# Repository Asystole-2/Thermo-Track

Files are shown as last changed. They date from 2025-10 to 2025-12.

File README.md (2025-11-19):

# 🌡️ ThermoTrack

<div align="center">

**Smart Environmental Monitoring System**

*A universally designed smart monitoring system that observes room occupancy, temperature, and humidity to provide intelligent HVAC recommendations*





</div>

---

## ✨ Features

| Feature | Description |
|---|---|
| 🔐 **Secure Authentication** | Hashed passwords with HTTPS encryption |
| 🧠 **Smart HVAC Recommendations** | AI-driven suggestions based on occupancy and environmental data |
| 📊 **Real-time Dashboard** | Live monitoring of temperature, humidity, and occupancy |
| ⚡ **Energy Efficiency** | Promotes energy savings through intelligent recommendations |
| 👨‍💼 **Admin Policies** | Customizable comfort settings and energy-saving rules |
| 📱 **Universal Design** | Accessible and responsive for all users |

---

## 🛠️ Technology Stack

### **Frontend & Styling**




### **Backend & Database**




### **Hardware & Sensors**




### **Communication & Security**




---

## 🚀 Quick Start

### **Web Application Setup**

```bash
# Clone the repository
git clone https://github.com/Asystole-2/Thermo-Track.git
cd ThermoTrack/src/web

# Create virtual environment
python -m venv venv

# Activate virtual environment (Windows)
venv\Scripts\activate

# Install dependencies
pip install flask flask-mysqldb python-dotenv flask-session

# Run the application
flask run

# Clone the repository
git clone https://github.com/Asystole-2/Thermo-Track.git
cd Thermo-Track

# Install Raspberry Pi GPIO
sudo apt install -y python3-rpi.gpio

# Create and activate virtual environment
python3 -m venv venv
source venv/bin/activate

# Install dependencies
pip install -U pip
pip install python-dotenv 'pubnub>=10.4.1'

# Set up environment variables
cp .env.example .env
nano .env  # Add your PUBNUB keys

# Set Python path
export PYTHONPATH="$PWD/src"
```
---

## DHT22 Setup
```bash

DHT22 Pin → Raspberry Pi Pin
─────────────────────────────
VCC (Pin 1)   → 3.3V Power (Pin 1)
Data (Pin 2)  → GPIO 4 (Pin 7)
Ground (Pin 4) → Ground (Pin 6)

# Update package list
sudo apt-get update

# Install Python headers and GPIO dependencies
sudo apt-get install python3-dev libgpiod-dev -y

# Install required Python libraries
pip3 install adafruit-circuitpython-dht Adafruit-Blinka pubnub
```
---

### **🤖 AI Condition Suggester**
```bash
The AI-powered condition suggester analyzes real-time
environmental data (temperature, humidity, occupancy)
combined with local weather forecasts to provide
intelligent HVAC recommendations.
It uses Googles Gemini AI to generate
context-aware suggestions for optimal
comfort and energy efficiency.

# Install AI and weather dependencies
pip install google-generativeai requests python-dotenv

# Or install all dependencies at once:
pip install google-generativeai requests python-dotenv

# API Configuration
# AI and Weather API Keys
GEMINI_API_KEY=your_gemini_api_key_here
OPENWEATHER_API_KEY=your_openweather_api_key_here

# Optional: Default location for weather data
DEFAULT_CITY=Dublin
DEFAULT_COUNTRY=IE

🔑 Obtaining API Keys

-Google Gemini API
Visit Google AI Studio

Sign in with your Google account

Click "Create API Key" in the sidebar

Copy the generated key and add it to your .env file as GEMINI_API_KEY

-OpenWeather API
Register at OpenWeatherMap

Verify your email address

Navigate to the "API Keys" tab in your dashboard

Generate a new key (free tier includes 1,000 calls/day)

Copy the key and add it to your .env file as OPENWEATHER_API_KEY

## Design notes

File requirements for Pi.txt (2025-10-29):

sudo apt update
#install git
sudo apt install -y git
#clone repository
cd ~
git clone https://github.com/Asystole-2/Thermo-Track.git
cd Thermo-Track
# make sure you are in the right branch
#install Raspberry Pi GPIO
sudo apt install -y python3-rpi.gpio python3-dev gcc
#create and activate your virtual environment
python3 -m venv venv
source venv/bin/activate
#Install dependencies
pip install -U pip
pip install python-dotenv
pip install 'pubnub>=10.4.1'
#create .env check the .env.example file copy paste that one change only the PUBNUB_PUBLISH_KEY and PUBNUB_SUBSCRIBE_KEY with your key
nano .env
#next set your path
export PYTHONPATH="$PWD/src"
#final step run motion 
python src/run_motion.py

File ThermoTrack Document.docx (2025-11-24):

## Thermo-Track: Smart HVAC Monitoring System

(SD3A: Moses-Ailemen David Ibukunoluwa, Eyob Gebrekidan, Tanatswa Ben Musemburi)

# Project Description

Thermo-Track is a smart monitoring system designed for educational institutions to optimize HVAC performance based on real-time occupancy and conditions.

Instead of directly controlling the Building Management System (BMS), Thermo-Track uses sensor data to generate smart, prioritized recommendations for condition adjustments. The project has been scaled down to focus on the educational environment where the balance between occupant comfort, energy efficiency, and limited user control is most critical.

Environment: Educational Establishments

We target universities, secondary, and primary schools where occupants (students/teachers) have no direct control over room temperatures but are significantly impacted by poor conditions.

- Goal: To create a self-regulating environment where comfort issues are solved before they lead to complaints or manual intervention.
- How: By continuously monitoring room occupancy and feeding real-time adjustment suggestions to the central BMS, Thermo-Track ensures spaces are never too hot or cold when occupied, and no energy is wasted on empty rooms.
- Result: Those with control (Facilities Managers) can direct energy efficiently, while occupants (Lecturers/Students) enjoy consistent comfort without needing to intervene.

Key Users: Roles and Access

The system's full functionality is limited to staff responsible for the building's operation and maintenance.

- Primary Users (Full Access): Facilities Managers use the system to monitor data, set energy policies, manage equipment, and approve system recommendations.
- Secondary User (Feedback Access): Lecturers/Teachers act as key witnesses and bridges for student comfort. They are given a simple interface to provide real-time feedback (e.g., "Too Warm") or suggest temperature preferences, which inform the Facilities Manager's actions and future system policies.

# Personas and Use Cases

Given the refined scope, here are three tailored personas representing the key users, along with a specific use case for each.

Persona 1: Facilities Manager — Daniel Murphy

Detail | Description
Focus | Energy Efficiency & Cost Control
Context | Daniel manages HVAC for the entire university campus. His core mandate is to cut the large energy bill while avoiding comfort-related staff/student complaints.
Pain Point | Rooms often retain climate control schedules from previous semesters, leading to AC running in empty lecture halls, resulting in high waste and no data to justify changes.
Quote | "I need data that proves exactly how much money I'm saving by cooling an empty room, so I can secure more budget."
Top Task | Identifying high-waste zones and setting campus-wide HVAC setback policies.

Use Case: Automated Energy Setback

1. Goal: Reduce energy waste in rooms that are empty between scheduled classes.
2. Scenario: Daniel uses the Thermo-Track dashboard to define a policy: if occupancy is zero for 15 minutes in a scheduled-to-be-occupied room, the system recommends a temperature setback to the BMS.
3. Action: The system applies the setback. When occupancy returns (a student arrives early), the system instantly recommends returning to the comfort setpoint.
4. Result: Daniel downloads a monthly report showing a reduction in energy across non-utilized spaces, which he uses to justify the project's return on investment.

Persona 2: Room Host (Lecturer) Lucy Lue

Detail | Description
Focus | Immediate Comfort Feedback & Class Focus
Context | Lucy teaches several classes a day. She is a secondary user with no access to the thermostat, but she's the first person to hear about comfort issues from students.
Pain Point | Students complain about the room being too cold or hot, but she has no way to fix it quickly. When she calls facilities, it takes hours for a technician to respond, disrupting her lesson.
Quote | "I need a quick, simple way to tell the building something's wrong so I can get back to teaching."
Top Task | Submitting comfort feedback during a lecture without disrupting the class.

Use Case: Low-Friction Comfort Nudge

1. Goal: Quickly communicate a comfort issue to the facilities team without making a phone call or leaving the class.
2. Scenario: Ten minutes into a lecture, students indicate the room is getting too warm. Lucy opens the Thermo-Track mobile interface via a dedicated room QR code.
3. Action: She sees the live room temperature and taps the "Too Warm" button. The system registers this as a priority comfort feedback point and automatically sends a recommendation to Daniel's team to slightly adjust the setpoint.
4. Result: Lucy gets an instant confirmation: "Adjustment requested and is being reviewed by Facilities." The room temperature stabilizes within 15 minutes, allowing Lucy to maintain focus on her class.

# User Flow

Task Analysis

This task analysis identifies the goals and the actions users (Lucy Lue - Lecturer; and Daniel Murphy - Facilities Manager) must take within the system to achieve them, based on their defined user roles and access levels.

1. Persona: Lucy Lue (Lecturer / Room Host)

Access Level: Basic User (Limited, feedback-only access via mobile/QR code)

User Type | Goal Description | Task Progression
Basic User | Submit Comfort Feedback (Too Warm/Cool) | Scan Room QR Code -> Mobile UI Opens -> View Live Temp/Status -> Tap "Too Warm" or "Too Cool" (Optional) Add Comment -> Tap Submit -> Receive Confirmation/ETA.
Basic User | Check Status after Submission | Scan Room QR Code (or stay on page) -> View status message (e.g., "Adjustment in Progress: ETA 5 min").
Basic User | Provide Feedback on Change | Scan Room QR Code -> View prompt (e.g., "Did the change help?") -> Select "Better" / "Worse" / "No Change" -> Tap Submit.
Basic User | View Current Room Conditions | Scan Room QR Code -> Mobile UI Opens -> View Live Temperature and Comfort Indicator

2. Persona: Daniel Murphy (Facilities Manager)

Access Level: Admin (Full Control)

User Type | Goal Description | Task Progression
Admin | Review Energy Waste/Savings | Log In -> Navigate to Dashboard -> Filter by "High Waste Zones" -> View Utilization vs. Condition Status -> Review Savings Metric.
Admin | Set Occupancy Setback Policy | Log In -> Navigate to Rules Engine/Policies ->Create New Policy Define Condition (e.g., "Occupancy = 0 for 15 min") -> Define Action (e.g., "Set Back Temp ") -> Apply to Zone/Building.
Admin | Approve Lecturer's Comfort Nudge | Log In -> View Notification Panel (or Alert Feed) -> See "Comfort Nudge from Lucy Lue in L-Hall 3" -> Review Room Data (Temp, Occupancy, Setpoint) -> Select "Approve Nudge" or "Dismiss."
Admin | Integrate with BMS | Log In -> Navigate to Settings -> Select BMS Integration -> Input BMS API/Protocol Details (e.g., BACnet IP) -> Map Thermo-Track Setpoints to BMS Registers -> Test Connection.
Admin | Monitor System Health (Sensors/BMS) | Log In -> Navigate to Device Health tab -> View Status of Sensors (Online/Offline/Battery) and BMS Connection -> Acknowledge/Assign Error Alerts.

# The UI

These mock ups show the flow of the system when being used by a restricted user and the by an administrator. The data they both have access to is that which is return by the sensors. The passive infrared sensor returns activity in the room which determines its occupation status. While the DHT22 returns the temperature and humidity. Knowing the room conditions allows the occupants to return feedback based on the current conditions e.g. request for lower the room temperature if the room is too warm. Occupancy and room conditions allows the administrator to set the appropriate conditions for the room according to its state e.g. Turn off the heating in an empty room. The admin deals with the user’s feedback, approving or dismissing room requests. This extra data helps them set favourable conditions for the occupants.

The distinction between admin and regular user will be made upon logging in as their credentials will limit or permit certain access after being validated.

Mock ups

Main screens for the lecturer

Dashboard showing rooms

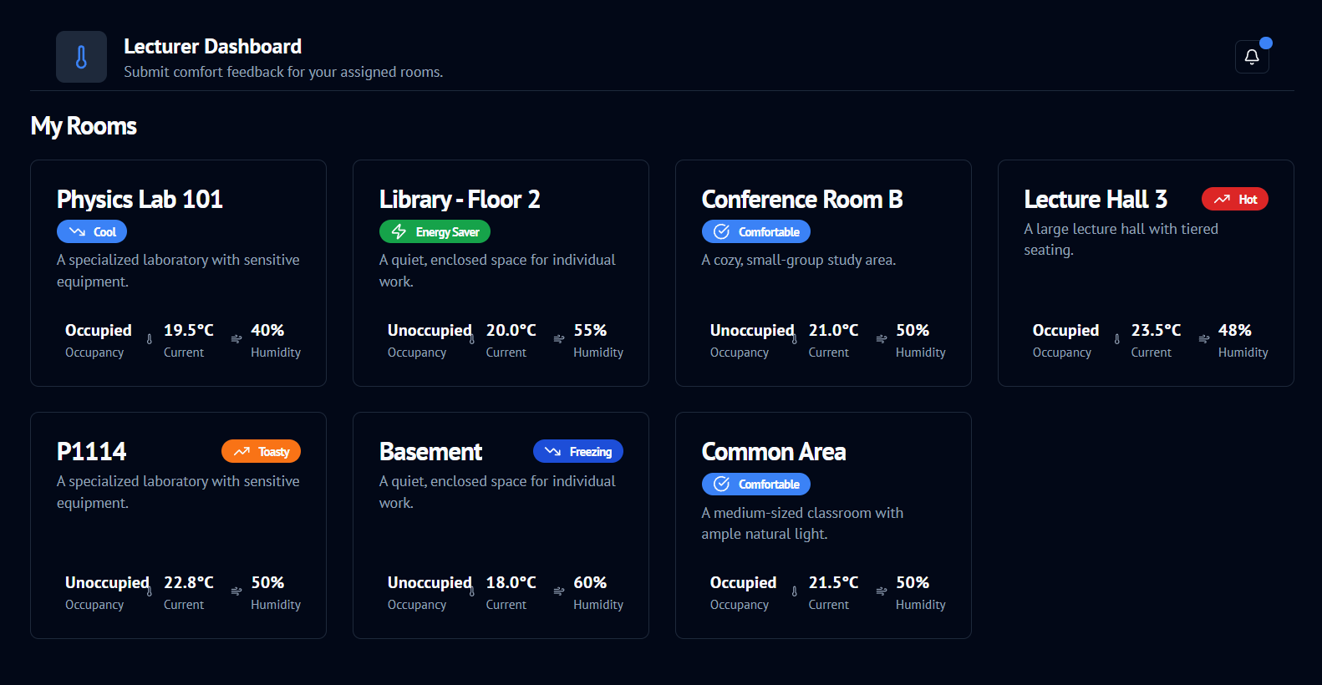
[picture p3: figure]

Lightmode:

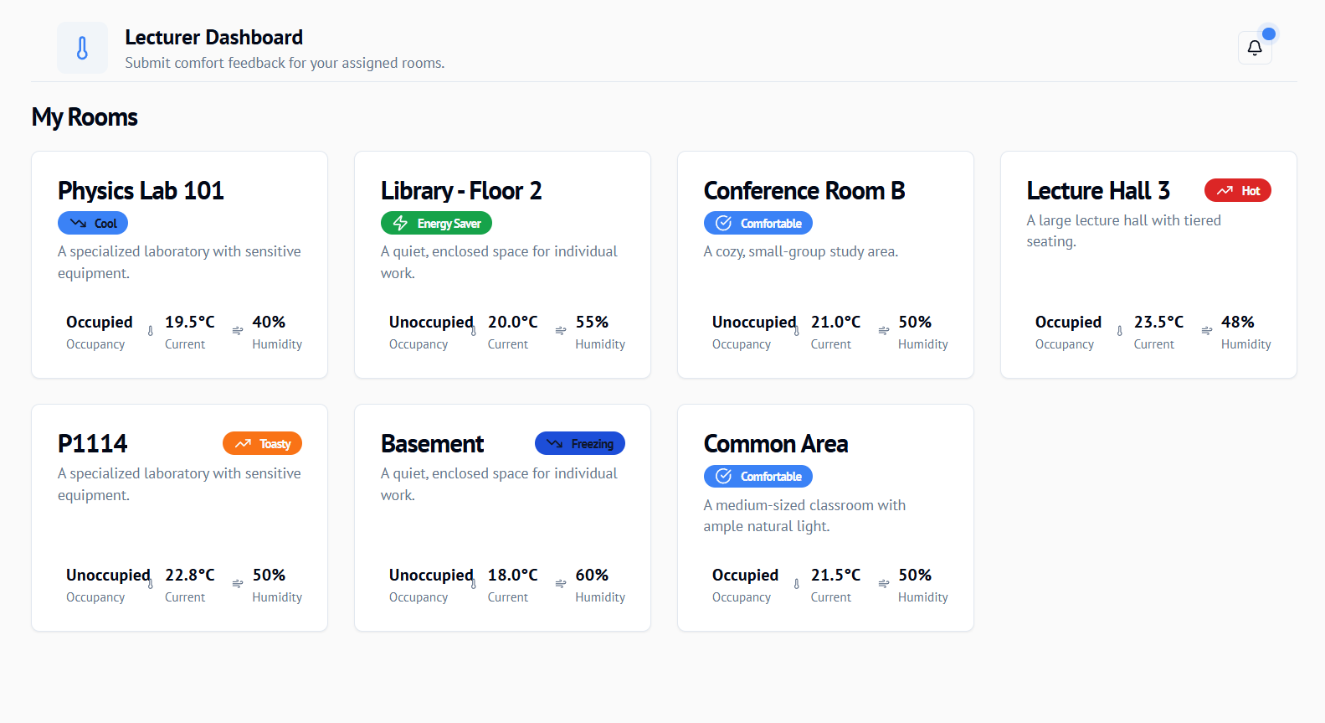
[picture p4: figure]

Room 114 was selected to give feedback on the room’s conditions. AI suggestions to help the user make a better decision since most will not know what temperature to input and what it will feel like when applied.

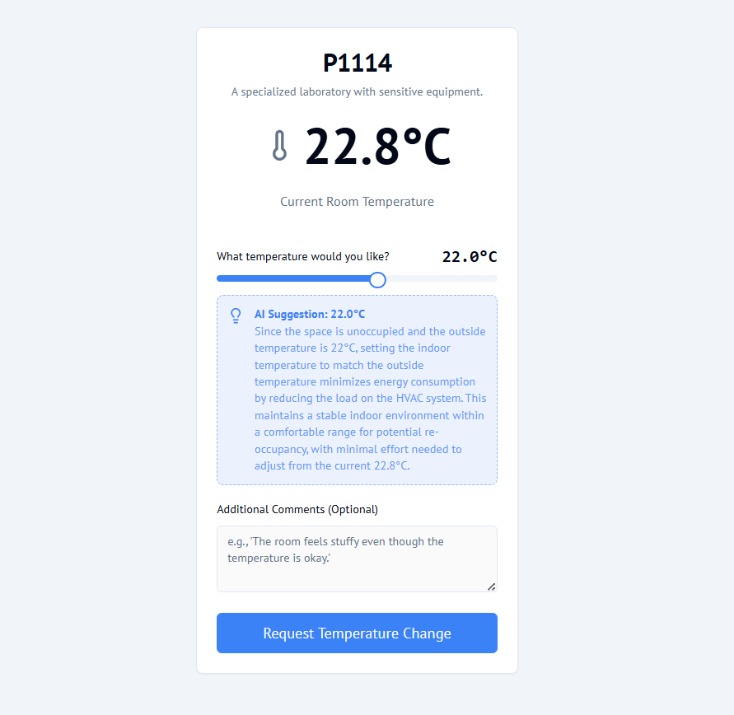
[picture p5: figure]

Dark mode view: The request is made for the room adjustments

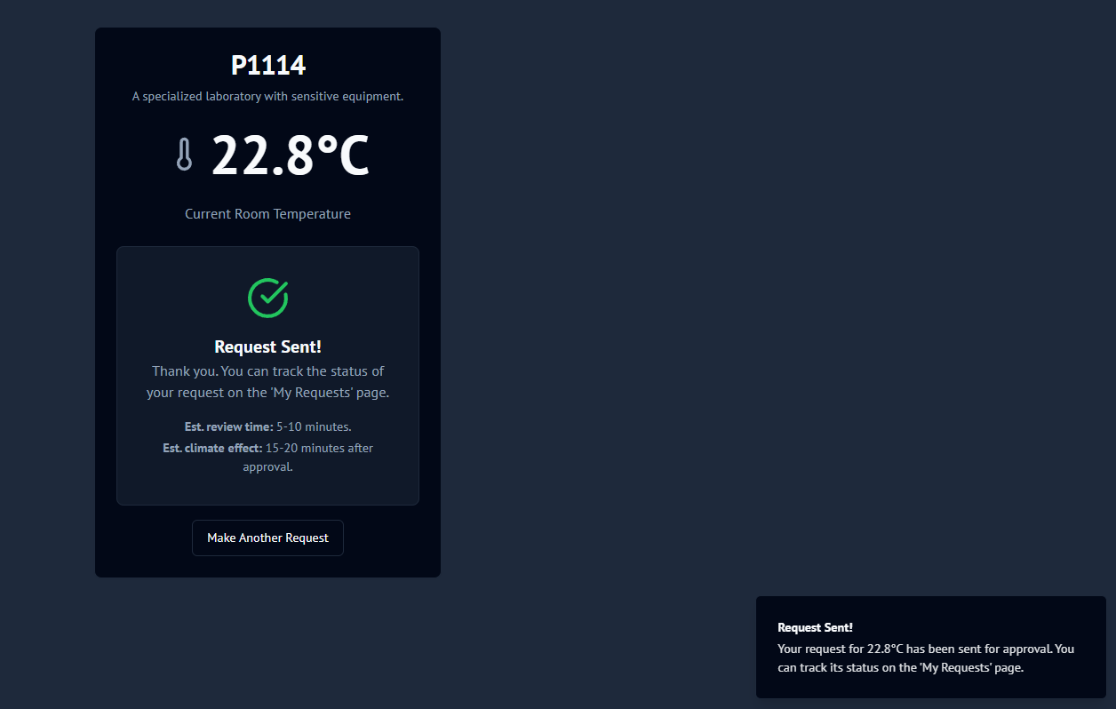
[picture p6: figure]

Tracking the request

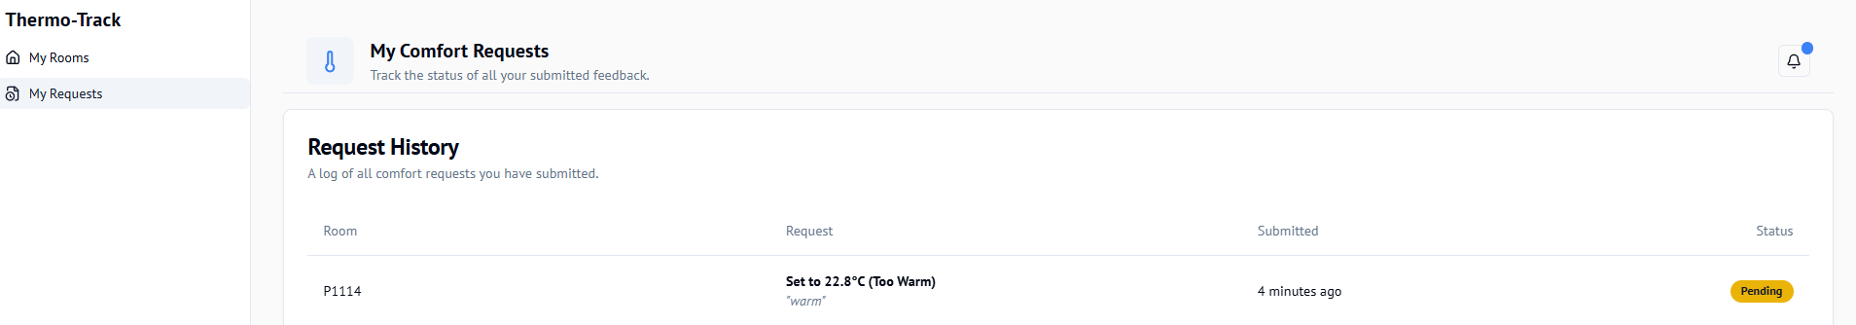
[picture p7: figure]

Main screens for the Facilities Manager (Admin)

The dashboard for the admin shows all the rooms as well as other features that come with full access (setup, reports, policies, settings).

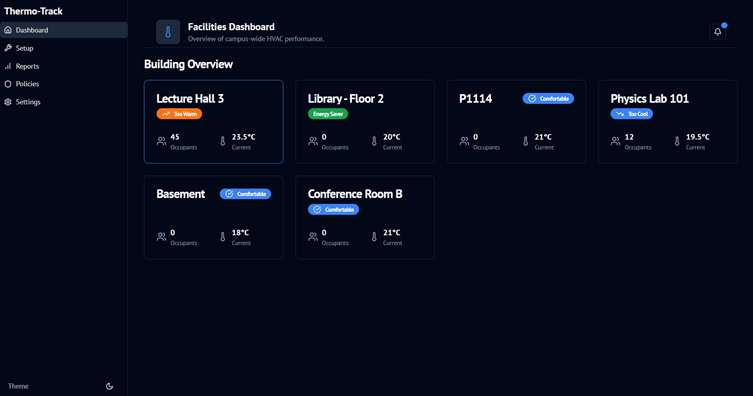
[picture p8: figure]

(slightly developed prototype that shows an overview of the building layout)

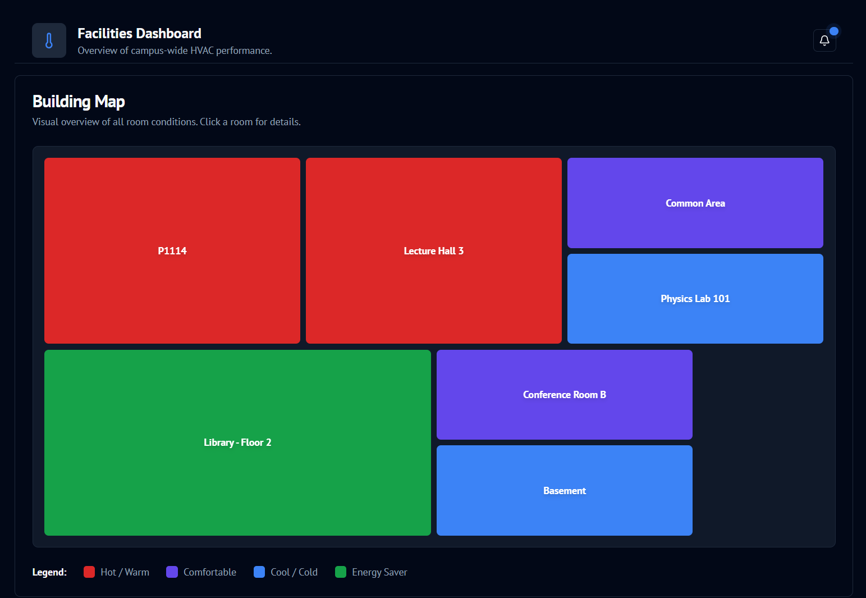
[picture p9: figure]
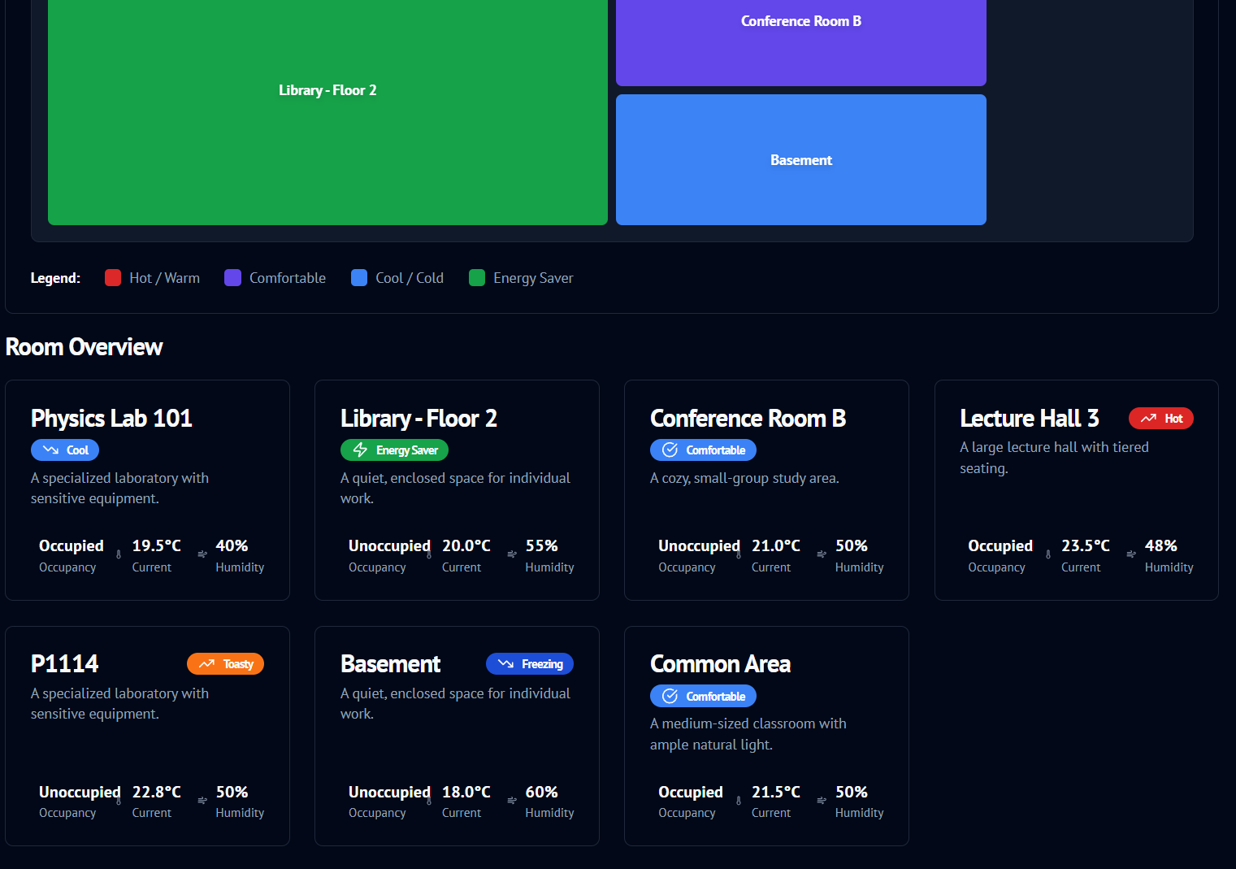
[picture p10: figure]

The dashboard in light mode

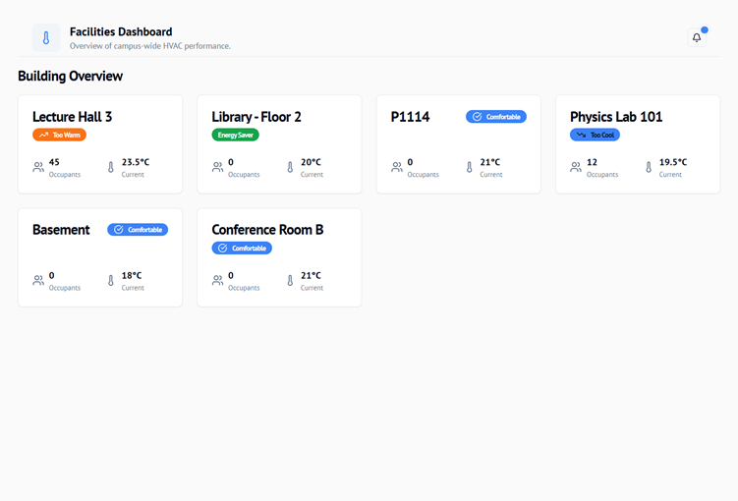
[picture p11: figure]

Improved version showing more room detail (the building overview above)

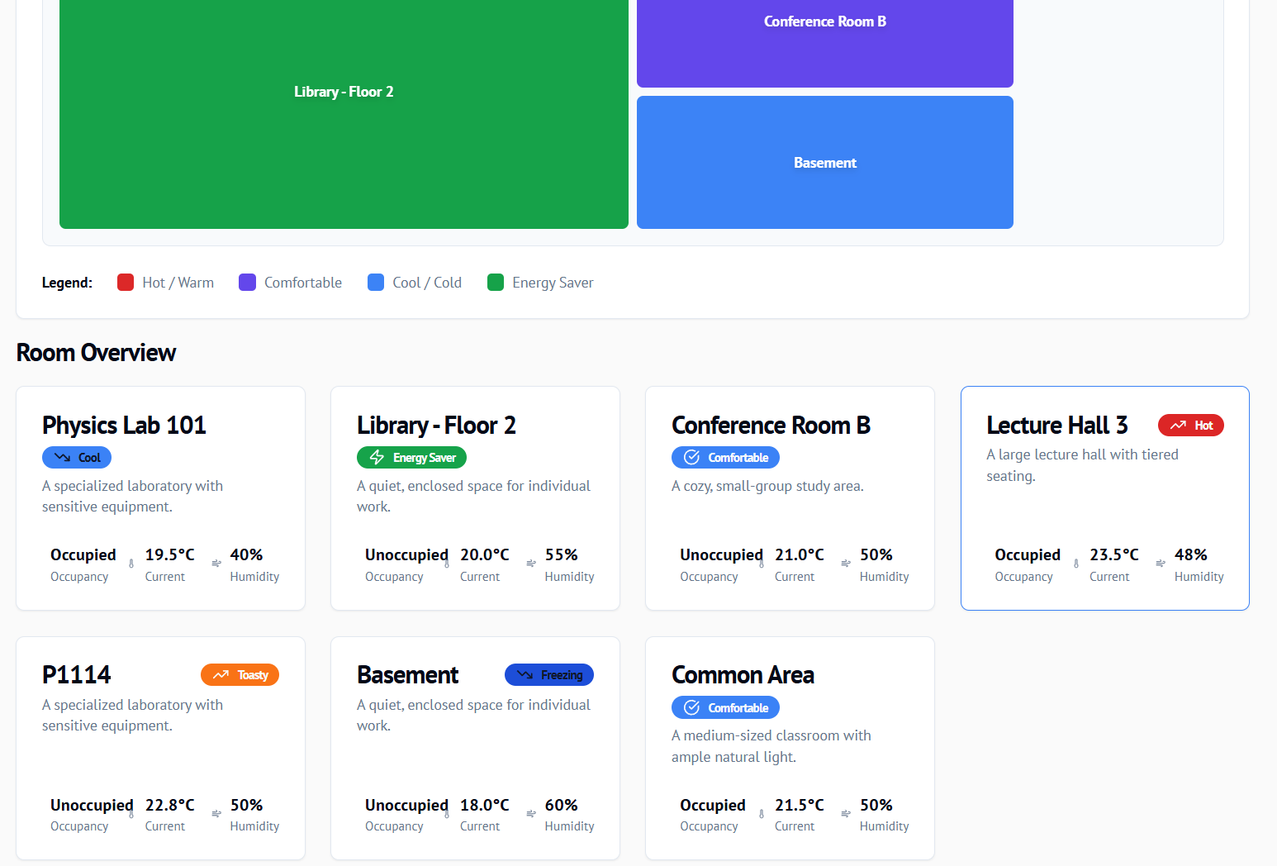
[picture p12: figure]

A single occupancy area selected then shown in detail (library floor 2)

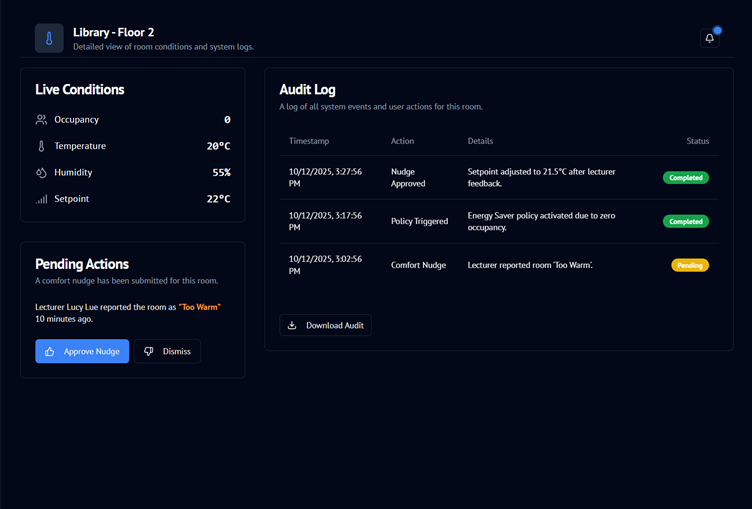
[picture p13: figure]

Improved version with a slider for quick manual configuration, accompanied by AI suggestion that recommends the best adjustment for the room

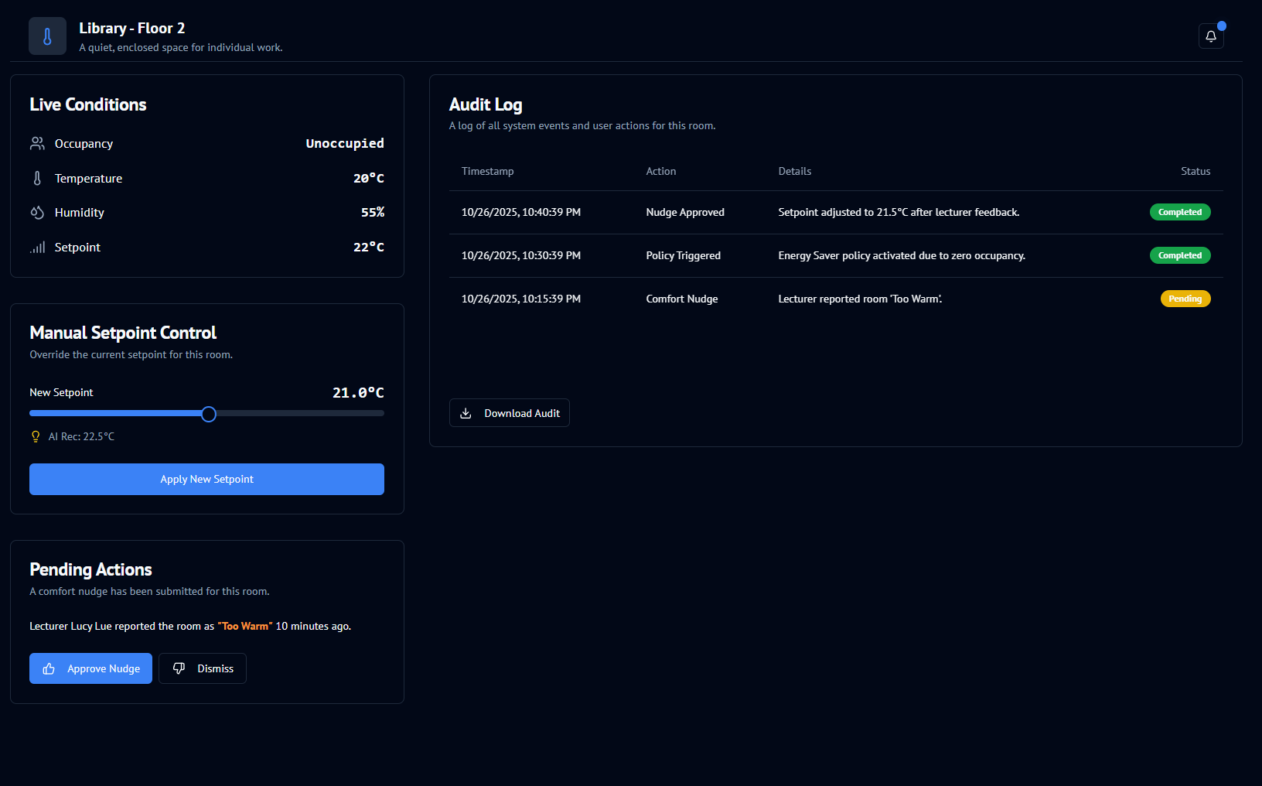
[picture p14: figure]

Display in light mode

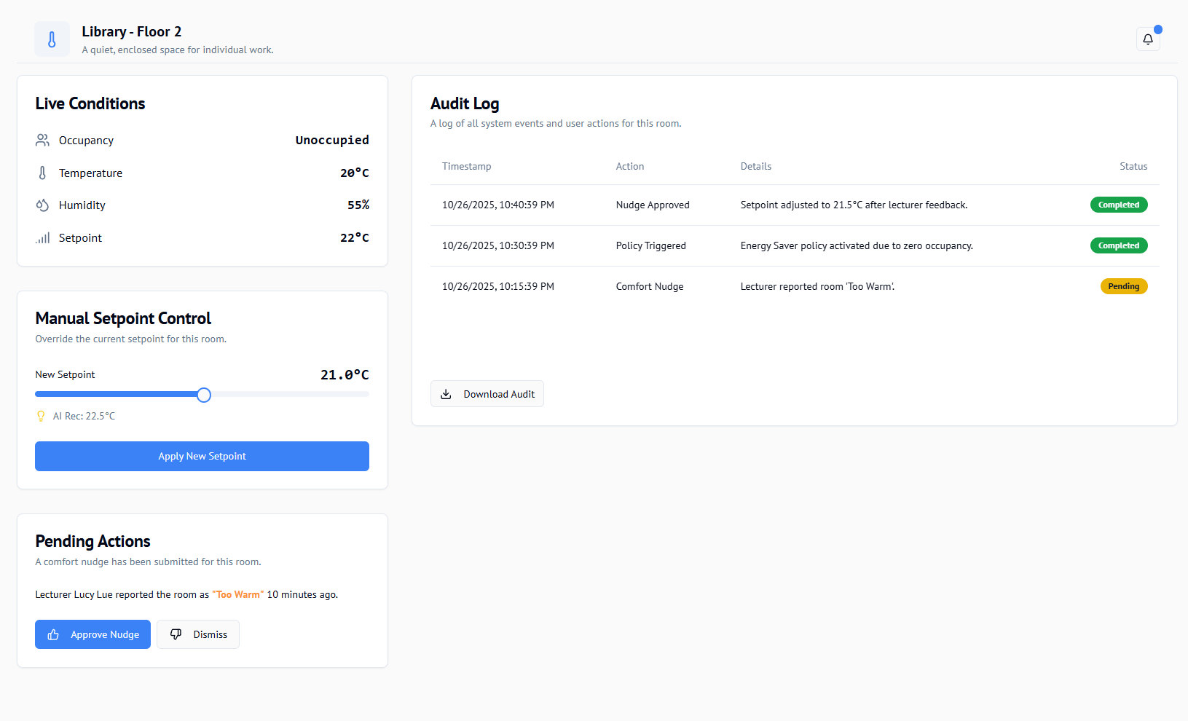
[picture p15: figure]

Notifications for room requests

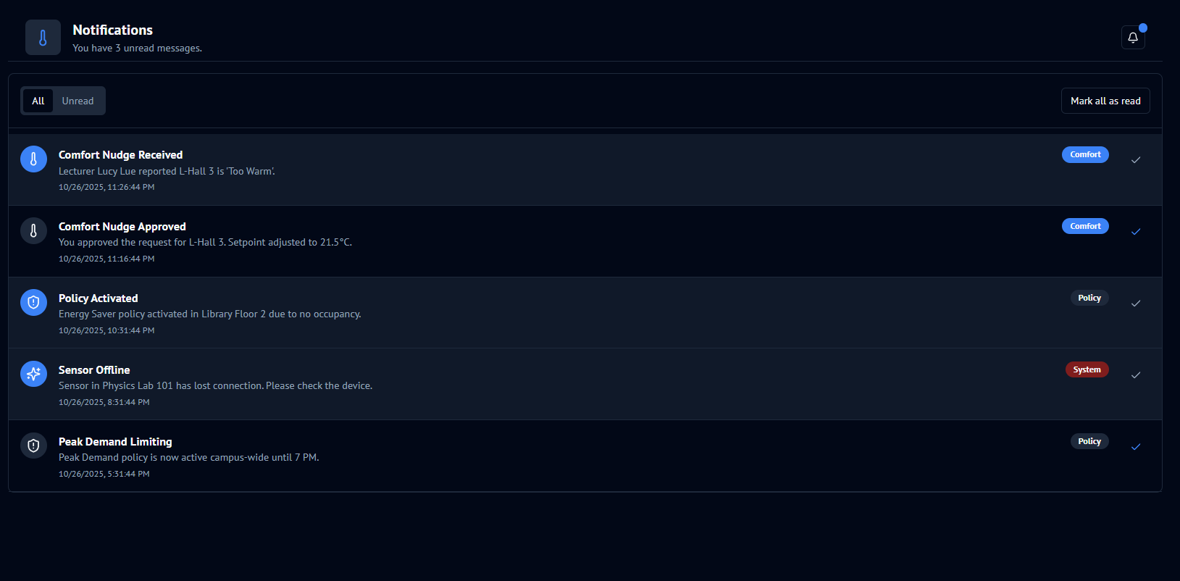
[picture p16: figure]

Screen for adding a new room

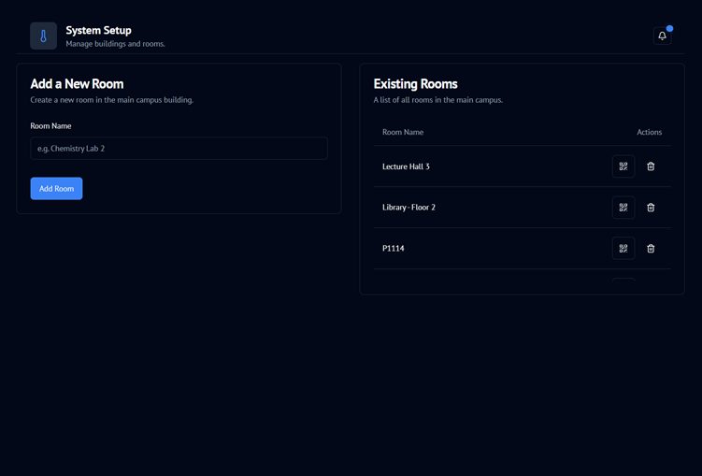
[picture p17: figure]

Screen to display reports (shows overview of the rooms being tracked + sensors)

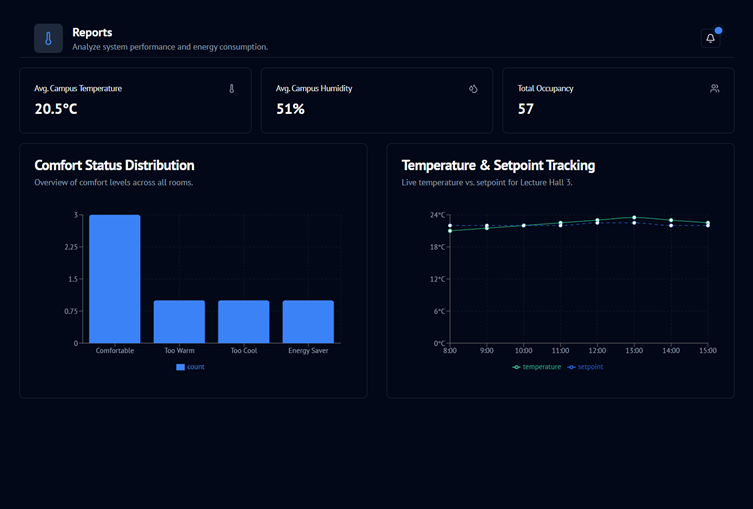
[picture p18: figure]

V2 (shows the additional room descriptions + sensors’ status’

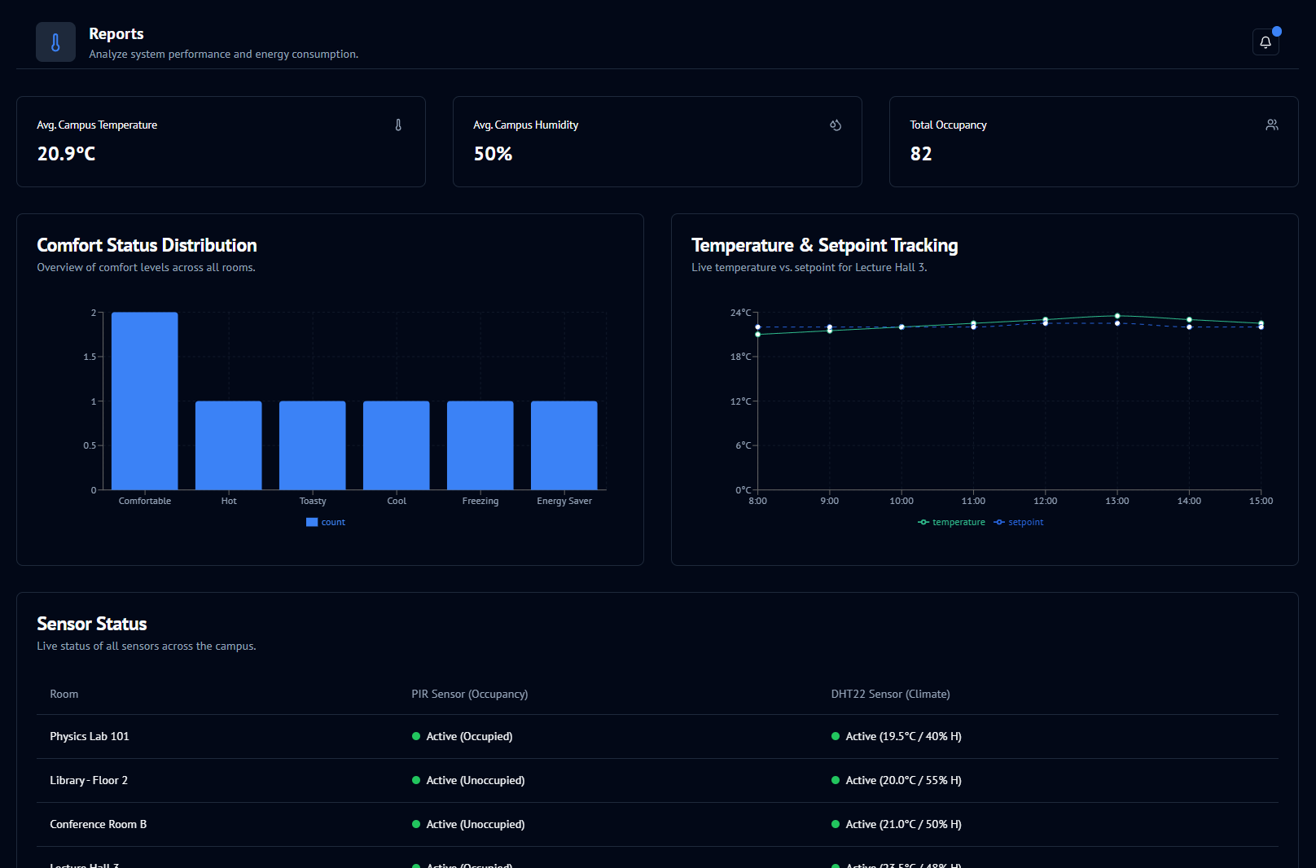
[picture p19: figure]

Screen showing policies

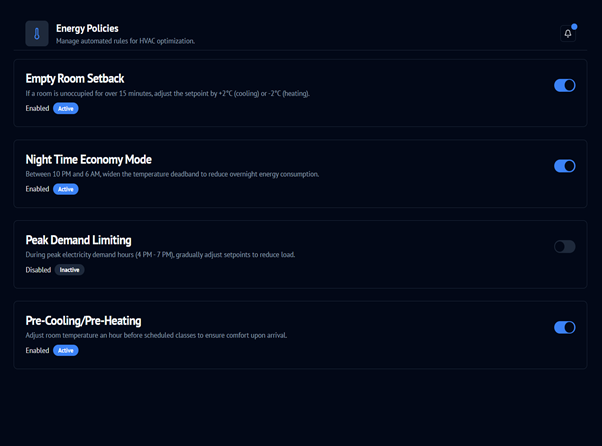
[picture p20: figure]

Settings display

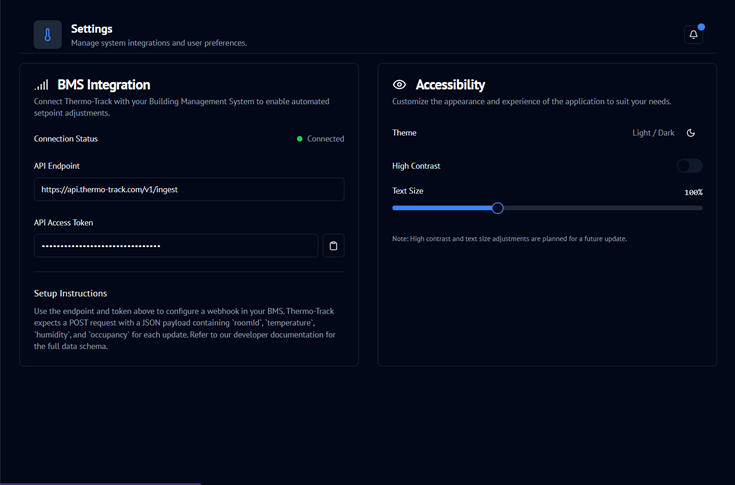
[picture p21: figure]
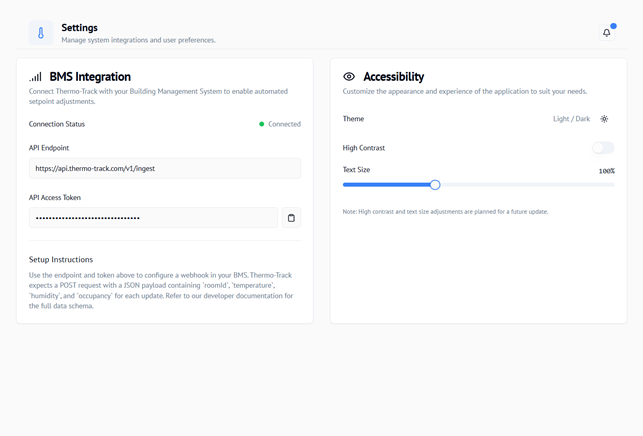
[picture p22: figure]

# Security Detail

Data Security

All data sent between the Thermo-Track device, web app and central server is protected.

- Data is encrypted so nobody can read it during transmission.
- PubNub is used for secure real time data transfer between IoT devices and the web app. PubNub built in end to end encryption, token based authentication and data integrity validation.
- Aws IotCore ensures devices are authenticated certificates before connecting to the cloud. Preventing fake or unauthorized devices from communicating.
- User’s logins on the web application are also protected HTTPS and secure cookies.

Data Security During Storage

When data reaches the server, it is stored safely in secured database (MariaDB)

- Sensitive information such as passwords is hashed and salted using algorithms like bcrypt so it cannot be read even if the database is compromised.
- All sensors and occupancy data stored AWS (MariaDB) is encrypted at rest using AWS manged keys.
- Data backups are encrypted and stored securely to prevent data loss.
- Access to the database is limited to authorized system components only.

All user and sensor data is stored following principle of the least privilege ensuring only required systems can access specific information.

Application level Security

- User’s roles determine what each user can view or modify such as Admin or standard users.
- Session management ensures that users are automatically logged out after inactivity to reduce unauthorized access.
- All web forms and API endpoints include server-side validation to ensure the data being sent is valid and secure.

Privacy and Data governance

- Only the minimum amount of data necessary for operation is collected.
- Access to personal or sensitive data is logged and reviewed periodically.
- All user actions and systems changes are logged for auditing and accountability.

# Thermo-Track Testing Plan

The Thermo-Track system will undergo both hardware and software testing to ensure the system performs accurately, securely and reliable.

The goal is to confirm that the device correctly detect occupancy, monitors environmental conditions and provides accurate smart recommendations for HVAC adjustments while maintaining user security and data privacy.

Testing Methods

Unit Testing (Software)

Each software component of the Thermo-Track web application and device logic will be tested individually to ensure it functions as expected.

Examples include:

- Testing login and registration forms for valid and invalid points.
- Verifying database connection and data retrieval

Success Criteria:

- All functions run without errors
- Input validation correctly blocks invalid data.
- Data is accurately stored and retrieved from the database

Integration Testing

Once individual parts work they will be tested together to ensure that smooth communication between:

- The device raspberry Pi and the web server.
- The database and the web interface.

Success Criteria:

- Data from the sensors is correctly sent to the server and displayed in the dashboard.
- User inputs correctly update the database.
- Communication remains stable with no data loss or timeouts.

System Testing

This will test the entire system Thermo-Track system from end to end. Combining hardware, network and software.

User Testing

This involves testing Thermo-Track with real users like students or staff to ensure it is easy to use, accessible and meets the intended goals.

- The web interface usability and accessibility.
- The accuracy of occupancy and comfort recommendations.

Success criteria:

- Feedback confirms that the system provides useful and understandable recommendations.
- Users can complete main task’s view data, adjust preferences, read recommendations without help.

# Thermo-Track Hardware detail

Thermo-track: A universally designed system that monitors room occupancy and conditions (temp adjustments) to provide smart recommendations for HVAC systems, instead of direct control. In a situation where adjustments are still desired, the system provides an easy and convenient way to change room HVAC settings or request alterations.

Component Breakdown

Controller (Logic)

- Raspberry Pi 400: This is the high-performance central processing unit. Since it's built into a keyboard, it offers a complete, robust platform for running the Python monitoring script, connecting to the internet via Wi-Fi or Ethernet, and managing the GPIO interfaces

Sensors (Input Data)

These components collect data about the environment and feed it back to the Thermo-Track application.

- DHT22 (Temperature & Humidity Sensor): Provides the core data for the application's primary function, tracking thermal conditions.
- PIR Sensor (Passive Infrared): Detects motion, useful for presence-based policy activation

Actuators (Output Action)

These components are controlled by the Thermo-Track policies to regulate or alert based on the sensor data.

- DFR0332 Fan Module: A dedicated cooling actuator.
- LED: A binary actuator for visual status confirmation (e.g., policy compliant/non-compliant). It can signal the status of the cooling fan (Green=Off, Red=On) or a compliance alert.
- Piezo Buzzer: The audible alert actuator, used to signal critical temperature breaches or policy violations.

Local Interface (Control & Enclosure)

The ABS Plastic Project Enclosures will house the entire system. The buttons, Fan, and Piezo Buzzer will be mounted directly into cutouts in the enclosure, providing a clean, finished appearance for the Thermo-Track monitoring station.

Power and Internet Connectivity

Power Supply

- Controller (Pi 400): The Raspberry Pi 400 is powered by a USB-C power supply. This is required for stable operation and is connected to the dedicated power port on the back. A power bank (<= 5.1v × 3A) can be used to power the pi 400 in the absence of a powered socket.
- Hardware Power:
  - Low-Power Components (Sensors, LED, Buzzer): These are powered safely and directly by the Pi's internal voltage regulators through the 3.3V GPIO Pin.
  - DFR0332 Fan Module: The fan module requires external power that may be greater than the current limit of the 3.3V pin. We will use the Pi's 5V GPIO Pin to power the module, and the Pi's 3.3V GPIO Pin will safely send the low-voltage control signal to the module's dedicated signal pin. The module's internal circuitry handles the switching of the higher 5V current, protecting the Pi.

Internet Connectivity

- The Pi 400 is an extremely reliable network device, offering two options:
  - Wi-Fi (Wireless): The Pi is configured to join the local Wi-Fi network using the graphical interface or command line tools.
  - Ethernet (Wired): The Pi 400 also has a full-sized Ethernet port, providing the most stable and low-latency connection, which is ideal for a critical monitoring application like Thermo-Track.
- Communication: Once connected, the Python script running on the Pi uses standard network libraries to send sensor data (Temperature, Humidity, Motion, Light) as HTTP POST requests over the internet to the remote Flask application. The application then uses the same network connection to send HTTP GET/POST control commands back to a server running on the Pi when an actuator needs to be triggered.

# Thermo-Track Data detail

Data captured, storage, and processing

Sensors & sampling

- DHT22 (temp/humidity)
  - Sampling: every 30s (configurable 10–60s).
  - Payload fields: temperature_c (float), humidity_pct (float).
  - Local sanity checks: drop values outside −20 - 60 °C or 0 -100 % RH.
- PIR motion
  - Event-driven; sampled every 1s to debounce.
  - A motion window (e.g., 15s) sets motion_detected = 1 on the next reading row for the same device (cheap to store).
- Device heartbeat
  - Every 60s; updates devices.last_seen_at.

End-to-end data flow

1. Acquire (Edge)
  a. DHT22 (temp/humidity) every 30s; PIR motion debounced at 1s and folded into the next reading.
  b. Edge validates ranges (−20…60 °C, 0–100 % RH) and adds device_serial + UTC timestamp.
2. Transmit (Edge → Server)
  a. HTTPS POST /api/v1/ingest with JSON: {"device_serial":"TT-DHT-003","ts":"2025-10-20T10:38:00Z","temperature":22.8,"humidity":47.2,"motion":0}
3. Ingest (Server)
  a. Resolve device_id by serial; reject unknown devices.
  b. Insert into readings(device_id, temperature, humidity, motion_detected, recorded_at) using parameterized SQL.
  c. Update devices.last_seen_at = NOW().
4. Process (Near-real-time + scheduled)
  a. Lightweight rules evaluate recent data for alerts and occupancy (see cron).
  b. Dashboard queries recent windows (last 5–30 min) and hourly rollups for charts.
5. Store & Retain
  a. Raw readings: keep 90 days, roll up hourly/day summaries, then archive or purge per policy.
  b. alerts kept 1 year, audit_log 6–12 months.

Cron jobs (Linux) / Task Scheduler (Windows)

All jobs are idempotent (safe to retry) and log to audit_log.

1) Housekeeping / Device health (every 5 min)

- Purpose: mark offline devices, backfill last_seen, clear stale temp files.
- Logic: devices.status='inactive' if last_seen_at < NOW()-INTERVAL 15 MINUTE.
- Cron: */5 * * * * /usr/bin/python3 tasks/housekeeping.py

2) Occupancy rollup (every 5 min)

- Purpose: derive recent occupancy per room from PIR motion.
- Logic: if any readings.motion_detected=1 in last 10–15 min → “occupied_recently”.
- Cron: */5 * * * * /usr/bin/python3 tasks/occupancy_rollup.py

3) Alert engine (every 5 min)

- Purpose: create alerts when comfort band is violated.
- Logic (example): if AVG(temperature) > 26°C for 10 min and occupied → insert alerts(room_id, message, severity).
- Cron: */5 * * * * /usr/bin/python3 tasks/alert_engine.py

4) Hourly rollup (at HH:05)

- Purpose: compress raw readings to hourly aggregates per room for charts.
- Output table (example): readings_hourly(room_id, hour_start, avg_temp, avg_humidity, motion_rate).
- Cron: 5 * * * * /usr/bin/python3 tasks/rollup_hourly.py

5) Daily retention & backup (02:15)

- Purpose: archive or purge raw rows older than 90 days, verify backup.
- Cron: 15 2 * * * /usr/bin/python3 tasks/retention.py

# Database Schema

CREATE DATABASE thermotrack;

USE thermotrack;

-- USERS: login + registration

CREATE TABLE users (

id INT AUTO_INCREMENT PRIMARY KEY,

username VARCHAR(100) NOT NULL UNIQUE,

email VARCHAR(255) NOT NULL UNIQUE,

password VARCHAR(255) NOT NULL,

created_at TIMESTAMP DEFAULT CURRENT_TIMESTAMP

);

-- ROOMS: physical spaces being monitored

CREATE TABLE rooms (

id INT AUTO_INCREMENT PRIMARY KEY,

name VARCHAR(100) NOT NULL,

location VARCHAR(255),

created_at TIMESTAMP DEFAULT CURRENT_TIMESTAMP

);

-- DEVICES: sensors installed in each room

CREATE TABLE devices (

id INT AUTO_INCREMENT PRIMARY KEY,

room_id INT NOT NULL,

name VARCHAR(100) NOT NULL,

type VARCHAR(50), -- e.g., 'Temperature', 'Humidity', 'Motion'

status VARCHAR(50) DEFAULT 'active',

installed_at TIMESTAMP DEFAULT CURRENT_TIMESTAMP,

FOREIGN KEY (room_id) REFERENCES rooms(id) ON DELETE CASCADE

);

-- READINGS: temperature, humidity, motion data

CREATE TABLE readings (

id INT AUTO_INCREMENT PRIMARY KEY,

device_id INT NOT NULL,

temperature FLOAT,

humidity FLOAT,

motion_detected BOOLEAN DEFAULT 0,

recorded_at TIMESTAMP DEFAULT CURRENT_TIMESTAMP,

FOREIGN KEY (device_id) REFERENCES devices(id) ON DELETE CASCADE

);

-- ALERTS: generated if readings exceed thresholds

CREATE TABLE alerts (

id INT AUTO_INCREMENT PRIMARY KEY,

room_id INT NOT NULL,

message VARCHAR(255) NOT NULL,

severity ENUM('info','warning','critical') DEFAULT 'info',

created_at TIMESTAMP DEFAULT CURRENT_TIMESTAMP,

FOREIGN KEY (room_id) REFERENCES rooms(id) ON DELETE CASCADE

);

-- AUDIT LOGS: tracks actions like login, logout, or alerts cleared

CREATE TABLE audit_log (

id INT AUTO_INCREMENT PRIMARY KEY,

user_id INT,

action VARCHAR(100) NOT NULL,

details TEXT,

created_at TIMESTAMP DEFAULT CURRENT_TIMESTAMP,

FOREIGN KEY (user_id) REFERENCES users(id) ON DELETE SET NULL

);

# Eyob Documentation

# AWS Deployment Summary

## Server Setup (AWS EC2)

- Created an EC2 instance (Ubuntu, t3.micro) on AWS
- Connected via PuTTY using the ppk key file for SSH access.
- Updated the server packages , installed necessary dependencies like python, venv, apache2….

## Flask Application Setup

- Uploaded the project files from the local machine to the EC2 instance using WinSCP.
- Activated the Python virtual environment
- Installed all required dependencies
- Renamed the Flask entry file to __init__.py and set up thermotrack.wsgi for Apache integration.

## Apache Web Server Configuration

- Created a new Apache site configuration file
- Added domain and WSGI settings
- Enabled the site and reloaded Apache

## Domain and SSL Setup

- Purchased a domain from GoDaddy Website name: thtrack.live
- Pointed a custom domain (thtrack.live) via GoDaddy to the AWS Elastic IP.
- Installed Certbot for free SSL(HTTPS):
  - sudo snap install certbot --classic
  - sudo apt install python3-certbot-apache
  - sudo certbot --apache -d thtrack.live -d www.thtrack.live

## Database Setup (MySQL)

- Installed and configured MySQL Server
- Created the database and tables for the project:
  - CREATE DATABASE thermotrack;
  - USE thermotrack;
- Updated .env with correct credentials
- Verified successful connection through Flask.

## Live Website Deployment

- The site was tested and verified at
  - https://thtrack.live/
- Backend Flask app runs under Apache via WSGI.
- HTTPS is enabled and auto-renewed by Certbot.
- MySQL database stores all user, room, and sensor data.
- Logs monitored using:
  - sudo tail -f /var/log/apache2/error.log
  - sudo tail -f /var/log/apache2/access.log

## Result

- The Flask web app was successfully deployed to a custom domain on AWS with HTTPS encryption.
- The website is fully functional and serves live data.

# Application Security

## Securing the IoT Device

The IoT hardware, such as a raspberry Pi connected to sensors, is secured using SSH key based authentication, disabling password based logins. This ensures that only authorized users can access the device remotely. The device communicates through PubNub encrypted channels. Preventing unauthorized interceptions or modification of sensor data. Sensitive credentials such as API keys are stored in hidden environments file ( .env ) rather than in the source code.

## Securing Communication Channels

Communication between the IoT devices, cloud services and the Flask web server uses Transport Layer Security (TLS). PubNub automatically encrypts all messages using HTTPS and over TLS, ensuring that environmental reading transmitted from the devices cannot be intercepted or altered during the transmission. Similarly, data sent from the web interface to the server is encrypted using HTTPS once the SSL certificate is installed via Certbot.

## Securing the Web Server

The Flask web application is deployed on an AWS EC2 Ubuntu instance configured with strict security rules. Only essential ports (22 for SSH and 443 for HTTPS) are open, while all others are blocked by AWS Security Groups. The web server runs under the non root ubuntu user for added isolation. The domain thtrack.live is protected by a Let’s Encrypt SSL certificate, which ensures all web traffic is encrypted and users connect securely.

## Securing the Database

The MySQL database is hosted locally within the EC2 instance and cannot be accessed externally. Application credentials for the database are securely loaded from environment variables defined in the .env file, preventing exposure in the codebase. User passwords are encrypted using Werkzeug’s generate_password_hash(), meaning no plaintext passwords are ever stored. This provides robust protection against data leaks or database compromise.

## Data at Rest and in Transit

All data stored in MySQL is protected through local access control and backups remain on the same secure server. Data in transit between IoT devices, web server and the browser is fully encrypted https and PubNub TLS channels. These measures collectively ensure confidentiality, integrity and availability across the entire ThermoTrack system.

## Issue: Fan Not Turning On/Off (Electrical Hardware Issue)

During initial testing, the fan would not turn ON or OFF even though the dashboard buttons were working correctly. The problem was not software related it was a hardware wiring/power issue.

Solution

ChatGPT gave me answer what the problem was

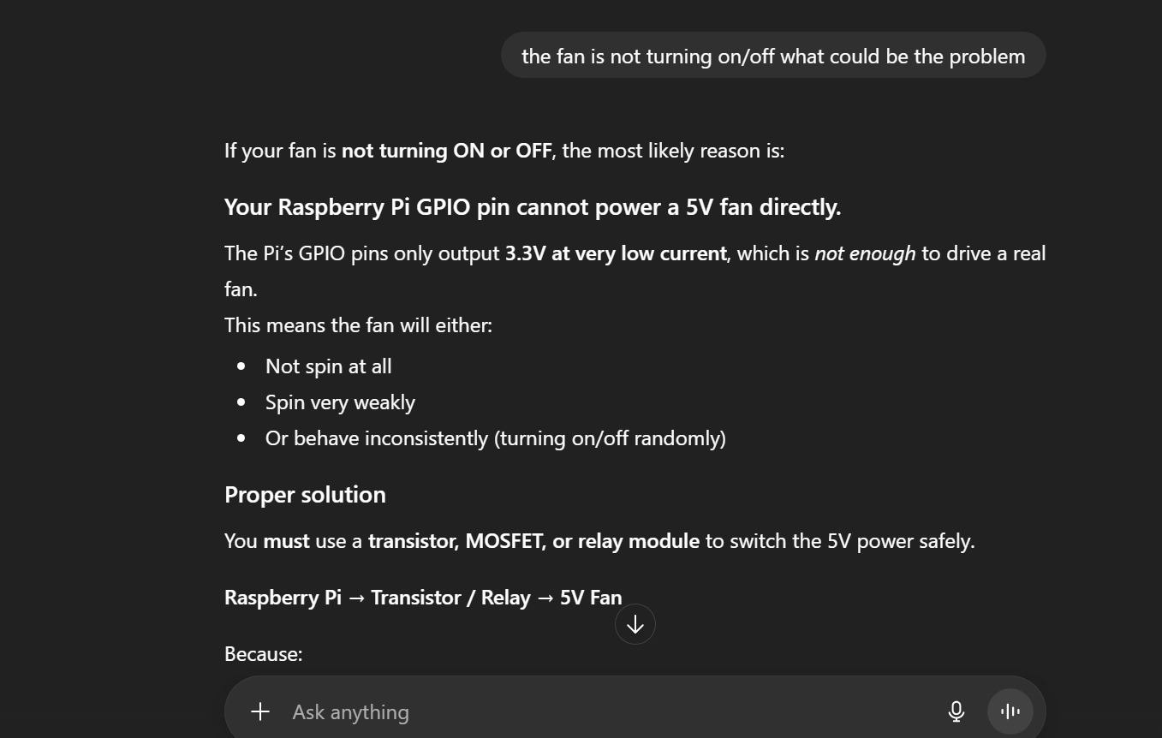
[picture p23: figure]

## GitHub merge conflict

During our project development each team member works on a separate branch to isolate features. However, when these branches are merged sometimes, we get conflicts in the same file or even in the same lines. Resolving these merge conflicts requires careful review to ensure no work is overwritten or lost, which can slow down development and introduce errors and it’s very frustrating if not handled correctly.

## ThermoTrack System Architecture Summary

ThermoTrack system uses IoT driven architecture where multiple physical sensors temperature and humidity (DHT22), motion (PIR), buzzer and fan/relay are connected to a raspberry Pi reads sensor data and communicates with the cloud using PubNub, publishing live events to the ThermoTrack channel and receiving real time control command fan on or fan off buzzer etc. From the backend. In the cloud layer and AWS EC2 UBUNTU server hots Flask backend. Which process user actions executes SQL queries on the MySQL database and sends control commands back to the Raspberry Pi via PubNub. The ThermoTrack web application ( www.thtrack.live ) connects to the backend to display live room conditions, manage user requests and allow admins or technicians to send hardware control commands. This creates a complete end to end from IoT sensors -> Raspberry Pi -> PubNub -> Cloud backend -> Web app ( www.thtrack.live ) -> back to IoT devices.

## PubNub Communication (Summary)

ThermoTrack uses PubNub as a real time messaging channel between the Raspberry Pi hardware and the web application. The Raspberry Pi publishes sensor data (temperature, humidity, and motion events) to the ThermoTrack PubNub channel and the website instantly receives and displays these updates. The website can also send control commands (like fan on or buzzer off) which the Raspberry Pi listens to in real time.

Below is an example of actual PubNub message used in ThermoTrack:

Motion Event

{

"channel": "ThermoTrack",

"timetoken": "17638481927443915",

"message": {

"event": "motion",

"device_uid": "pir_sensor_01",

"occupied": 1,

"at": 1763848192

},

"messageType": null,

"uuid": "ThermoTrack_Server"

}

Temperature and Humidity Reading

{"event":"dht22_reading","device_uid":"dht22_sensor_01","temperature_c":24.2,"humidity":47.3,"at":1763848195}

{

"channel": "ThermoTrack",

"timetoken": "17638481958855616",

"message": {

"event": "dht22_reading",

"device_uid": "dht22_sensor_01",

"temperature_c": 24.2,

"humidity": 47.3,

"at": 1763848195

},

"messageType": null,

"uuid": "ThermoTrack_Server"

}

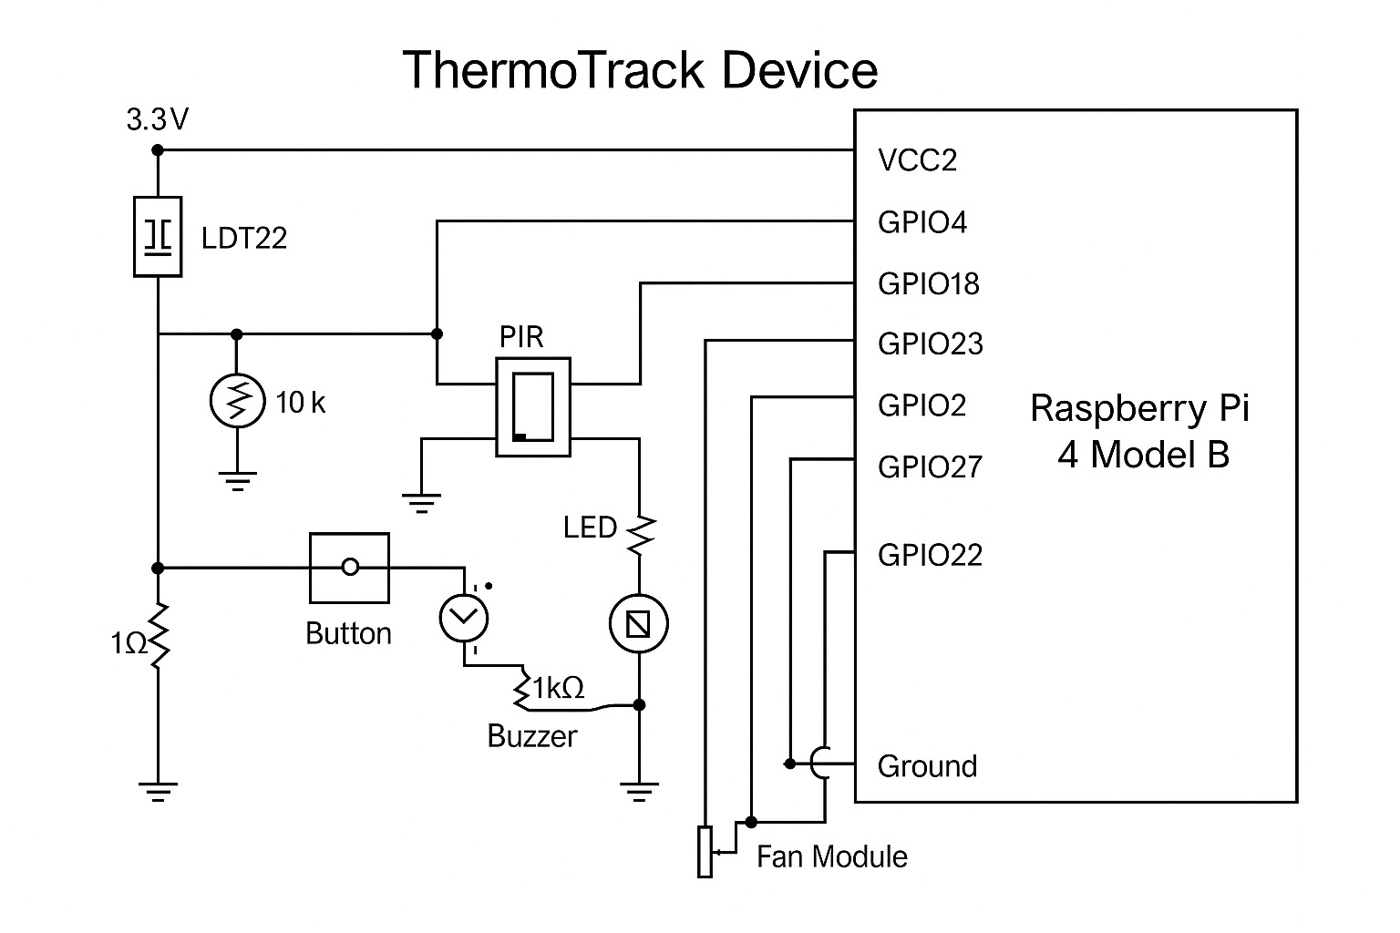
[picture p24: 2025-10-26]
Thermotrack Circuit diagram for 2nd fritzing diagram.jpg

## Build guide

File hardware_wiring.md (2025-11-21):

# Hardware Wiring Documentation

## Overview

This document contains the complete wiring details for the **ThermoTrack IoT System** including:

* PIR Motion Sensors
* DHT22 Temperature & Humidity Sensors
* Fan Control using GPIO
* Piezo Buzzer

This wiring guide is fully updated based on the final physical layout.

---

#  Raspberry Pi 4B/400 → Components Mapping

| Component | GPIO Pin | Physical Pin | Notes |
| --- | --- | --- | --- |
| **DHT22 Data** | GPIO 4 | Pin 7 | Uses 10k pull up resistor (already onboard) |
| **PIR Motion Sensor (OUT)** | GPIO 17  | Pin 11 | Trigger signal |
| **Piezo Buzzer (+)** | GPIO 27  | Pin 13 | Active buzzer |
| **Fan PWM / Control** | GPIO 14  | Pin 8 | Via NPN transistor |
| **3.3V Power** | — | Pin 1 / 17 | Powers PIR + DHT22 |
| **5V Power** | — | Pin 2 / 4 | Powers DC Fan |
| **GND** | — | Pin 6 / 9 / 14 / 20 | All grounds together |

---

#  Individual Component Wiring

##  DHT22 Sensor (Temperature + Humidity)

**Positions: e10, e11, e12, e13**

* **VCC → Pin 1 (3.3V)**
* **DATA → GPIO 4 (Pin 7)**
* **GND → Pin 6**
* Resistor board used: **b10, b11**

---

##  PIR Motion Sensors (e1, e2, e3)

### PIR Sensor A1 (Left Red Board)

* **OUT → GPIO 17 (Pin 11)**
* **VCC → 3.3V**
* **GND → Ground**

### PIR Sensor A2 (Middle Orange Board)

* **OUT → GPIO 31 (Not a GPIO — NOTE!)**
   *Pin 31 corresponds to GPIO 6 — confirm code if needed*

### PIR Sensor A3 (Right Brown Board)

* **OUT → GPIO 9**
   *Pin 21 corresponds to GPIO 9*

➡ If only **one PIR** is used in software, A1 is the primary.

---

##  Passive Piezo Buzzer (e16, e17)

### Blue board A16 → GPIO 14

### Purple board A17 → GPIO 12

**Final wiring used:**

* **Signal → GPIO 27 (Pin 13)**
* **GND → Pin 14/20**

---

##  Fan Control (DC Fan)

* **Red wire → Pin 2 (5V)**
* **Black wire → Pin 39 (GND)**

---

#  Notes & Safety

* Always power **sensors from 3.3V**, not 5V.
* All grounds must be connected together.

---

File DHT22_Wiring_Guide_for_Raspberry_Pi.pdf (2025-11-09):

# DHT22 Wiring Guide for Raspberry Pi (with Breadboard)

## 1■■ DHT22 Placement

Place the DHT22 so that its 4 pins sit in the breadboard at E10, E11, E12, E13. The flat side with the holes should face you. The pins from left to right are: 1) VCC (Power), 2) DATA (Signal), 3) NC (Not Connected), 4) GND (Ground).

## 2■■ Wiring Connections

- VCC (Pin 1) → A10 → Red wire → Raspberry Pi Pin 1 (3.3V)
- DATA (Pin 2) → A11 → Orange wire → Raspberry Pi Pin 7 (GPIO 4)
- NC (Pin 3) → A12 → Not used
- GND (Pin 4) → A13 → Brown wire → Raspberry Pi Pin 6 (GND)

## 3■■ Resistor (10 kΩ)

Use a 10 kΩ resistor (brown-black-orange-gold). Connect one leg of the resistor to B10 (VCC) and the other leg to B11 (DATA). This connects VCC to DATA for stable readings.

## 4■■ Python Code Setup

In your Python code, always use:

import board
import adafruit_dht

dht_device = adafruit_dht.DHT22(board.D4)

## 5■■ Summary

- Red → 3.3V (Pin 1)
- Orange → GPIO 4 (Pin 7)
- Brown → GND (Pin 6)
- 10 kΩ resistor → between DHT22 Pin 1 (VCC) and Pin 2 (DATA)

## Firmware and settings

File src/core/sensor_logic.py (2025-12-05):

import time
from typing import Optional

# --- Hardware Libraries ---
try:
    import RPi.GPIO as GPIO
except ImportError:

    class MockGPIO:
        BOARD, BCM, IN, OUT, LOW, HIGH = 1, 2, 3, 4, 0, 1
        PUD_DOWN, PUD_UP = 5, 6

        def setmode(self, mode):
            print(f"Mock GPIO: Set mode {mode}")

        def setup(self, pin, mode, initial=None, pull_up_down=None):
            print(f"Mock GPIO: Setup pin {pin} as {mode}")

        def output(self, pin, value):
            print(f"Mock GPIO: Pin {pin} → {'HIGH' if value else 'LOW'}")

        def input(self, pin):
            return 0

        def cleanup(self):
            print("Mock GPIO: Cleanup")

        def setwarnings(self, flag):
            print(f"Mock GPIO: Warnings {flag}")

    GPIO = MockGPIO()

try:
    import adafruit_dht
    import board
except ImportError:
    print("Warning: adafruit_dht or board not found. DHT reading skipped.")
    adafruit_dht = None
    board = None

# --- PubNub Client Import ---
try:
    from pubnub_client import publish_data, subscribe_to_updates
except ImportError:
    print("Warning: PubNub client missing (mock mode enabled)")

    def publish_data(data):
        print(f"[PubNub Mock] Would publish: {data}")

    def subscribe_to_updates(cb):
        print("[PubNub Mock] No real listener added")


# --- PIN CONFIGURATION ---
class PinConfig:
    PIR_PIN = 6
    DHT_PIN = 4
    BUZZER_PIN = 27
    LED_PIN = 22
    FAN_PIN = 17


# --- AUTO MODE SETTINGS ---
AUTO_MODE = True
AUTO_THRESHOLD = 24  # Fan ON at >= 24°C
LAST_MANUAL = 0  # Time manual button pressed
MANUAL_TIMEOUT = 10  # Auto mode resumes after 10 sec


# -----------------------
# SENSOR MONITOR CLASS
# -----------------------
class SmartHomeMonitor:

    def __init__(self):
        self._gpio = GPIO
        self.dht_device = None

        self._gpio.setwarnings(False)
        self._setup_gpio()
        self._setup_dht()
        self.buzzer_pwm = GPIO.PWM(PinConfig.BUZZER_PIN, 1000)
        self.buzzer_pwm.start(0)

        print("[Monitor] Components initialized.")

    # GPIO Setup
    def _setup_gpio(self):
        try:
            self._gpio.cleanup()
        except:
            pass

        self._gpio.setmode(self._gpio.BCM)

        self._gpio.setup(
            PinConfig.PIR_PIN, self._gpio.IN, pull_up_down=self._gpio.PUD_DOWN
        )
        self._gpio.setup(PinConfig.BUZZER_PIN, self._gpio.OUT, initial=self._gpio.LOW)
        self._gpio.setup(PinConfig.LED_PIN, self._gpio.OUT, initial=self._gpio.LOW)
        self._gpio.setup(PinConfig.FAN_PIN, self._gpio.OUT, initial=self._gpio.LOW)

        print("[Monitor] GPIO configured.")

    # DHT Setup
    def _setup_dht(self):
        if adafruit_dht and board:
            try:
                self.dht_device = adafruit_dht.DHT22(board.D4)
                print("[Monitor] DHT22 initialized.")
            except:
                print("[Monitor] DHT22 failed.")
                self.dht_device = None

    # Buzzer logic
    def beep_on_sound(self):
        """Short rising chirp"""
        for freq in [500, 700, 900, 1100]:
            self.buzzer_pwm.ChangeFrequency(freq)
            self.buzzer_pwm.ChangeDutyCycle(70)
            time.sleep(0.07)
        self.buzzer_pwm.ChangeDutyCycle(0)

    def beep_off_sound(self):
        """Short falling chirp"""
        for freq in [900, 700, 500]:
            self.buzzer_pwm.ChangeFrequency(freq)
            self.buzzer_pwm.ChangeDutyCycle(50)
            time.sleep(0.08)
        self.buzzer_pwm.ChangeDutyCycle(0)

    def _buzzer_loud_beep(self, repeat=2):
        self.beep_on_sound()

    # CMD Handler for PubNub
    def handle_command(self, msg: dict):
        global AUTO_MODE, LAST_MANUAL

        cmd = msg.get("cmd")
        print(f"[Pi] CMD Received → {cmd}")

        # turns off auto mode temporarily
        if cmd in ["fan_on", "Fan On"]:
            GPIO.output(PinConfig.FAN_PIN, GPIO.HIGH)
            print("[MANUAL] Fan ON")
            LAST_MANUAL = time.time()
            AUTO_MODE = False
            self.beep_on_sound()

        elif cmd in ["fan_off", "Fan Off"]:
            GPIO.output(PinConfig.FAN_PIN, GPIO.LOW)
            print("[MANUAL] Fan OFF")
            LAST_MANUAL = time.time()
            AUTO_MODE = False
            self.beep_off_sound()

        elif cmd == "buzzer_on":
            self.beep_on_sound()
            print("[MANUAL] Buzzer ON")

        elif cmd == "buzzer_off":
            self.beep_off_sound()
            print("[MANUAL] Buzzer OFF")

        elif cmd == "auto_on":
            AUTO_MODE = True
            print("[Pi] AUTO MODE ENABLED")

        elif cmd == "auto_off":
            AUTO_MODE = False
            print("[Pi] AUTO MODE DISABLED")

        else:
            print("[Pi] Unknown command")

    # AUTO FAN LOGIC
    def auto_fan(self, temp_c):
        if temp_c is None:
            return

        if temp_c >= AUTO_THRESHOLD:
            GPIO.output(PinConfig.FAN_PIN, GPIO.HIGH)
            print(f"[AUTO] Temp {temp_c}°C → FAN ON")
        else:
            GPIO.output(PinConfig.FAN_PIN, GPIO.LOW)
            print(f"[AUTO] Temp {temp_c}°C → FAN OFF")

    # MAIN LOOP
    def run(self):
        print("[Pi] Starting Smart Home Monitor...")
        subscribe_to_updates(self.handle_command)

        last_motion = GPIO.LOW
        last_motion_time = 0

        while True:
            ts = int(time.time())
            temp_c = None

            # Read DHT22
            if self.dht_device:
                try:
                    temp_c = self.dht_device.temperature
                    humidity = self.dht_device.humidity

                    if temp_c is not None:
                        publish_data(
                            {
                                "event": "dht22_reading",
                                "device_uid": "dht22_sensor_01",
                                "temperature_c": round(float(temp_c), 2),
                                "humidity": round(float(humidity), 2),
                                "at": ts,
                            }
                        )

                except Exception as e:
                    print(f"[DHT22] Error: {e}")

            # PIR Motion
            current_motion = GPIO.input(PinConfig.PIR_PIN)
            motion_detected = current_motion == GPIO.HIGH

            if motion_detected and last_motion == GPIO.LOW:
                print("[PIR] MOTION DETECTED")
                publish_data(
                    {
                        "event": "motion",
                        "device_uid": "pir_sensor_01",
                        "occupied": 1,
                        "at": ts,
                    }
                )
                GPIO.output(PinConfig.LED_PIN, GPIO.HIGH)
                # GPIO.output(PinConfig.BUZZER_PIN, GPIO.HIGH)
                # time.sleep(0.3)
                # GPIO.output(PinConfig.BUZZER_PIN, GPIO.LOW)
                self.beep_on_sound()

            elif not motion_detected and last_motion == GPIO.HIGH:
                if ts - last_motion_time >= 2:
                    print("[PIR] Motion stopped")
                    publish_data(
                        {
                            "event": "motion",
                            "device_uid": "pir_sensor_01",
                            "occupied": 0,
                            "at": ts,
                        }
                    )
                GPIO.output(PinConfig.LED_PIN, GPIO.LOW)

                self.beep_off_sound()

            last_motion = current_motion

            # FAN AUTO MODE with MANUAL TIMEOUT
            global AUTO_MODE
            if time.time() - LAST_MANUAL > MANUAL_TIMEOUT:
                AUTO_MODE = True

            if AUTO_MODE:
                self.auto_fan(temp_c)

            time.sleep(2)


# Run Monitor
if __name__ == "__main__":
    monitor = SmartHomeMonitor()
    monitor.run()

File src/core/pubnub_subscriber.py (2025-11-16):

import os
import sys
import time
from dotenv import load_dotenv, find_dotenv

# Add the project root to Python path
project_root = os.path.dirname(os.path.dirname(os.path.dirname(os.path.abspath(__file__))))
sys.path.insert(0, project_root)

# Now import your existing modules
from src.core.pubnub_client import create_pubnub_client, CHANNEL

# Import database utilities from your existing app
try:
    from app import mysql, db_cursor

    print("[Subscriber] Using existing Flask MySQL connection")
    USE_FLASK_DB = True
except ImportError:
    print("[Subscriber] Flask app not available, using direct MySQL connection")
    USE_FLASK_DB = False
    import mysql.connector

load_dotenv(find_dotenv())


class DatabaseHandler:
    def __init__(self):
        if USE_FLASK_DB:
            self.use_flask_db = True
        else:
            self.use_flask_db = False
            self.db_config = {
                'host': os.getenv("MYSQL_HOST"),
                'user': os.getenv("MYSQL_USER"),
                'password': os.getenv("MYSQL_PASSWORD"),
                'database': os.getenv("MYSQL_DB"),
                'port': int(os.getenv("MYSQL_PORT", "3306"))
            }

    def save_sensor_reading(self, device_uid, temperature=None, humidity=None, motion_detected=None):
        """Save sensor reading to database"""

        if self.use_flask_db:
            # Use existing Flask database connection
            return self._save_with_flask_db(device_uid, temperature, humidity, motion_detected)
        else:
            # Use direct MySQL connection
            return self._save_with_direct_db(device_uid, temperature, humidity, motion_detected)

    def _save_with_flask_db(self, device_uid, temperature, humidity, motion_detected):
        """Save using Flask's MySQL connection"""
        cursor = db_cursor()

        try:
            # Get or create device ID
            cursor.execute(
                "SELECT id, room_id FROM devices WHERE device_uid = %s",
                (device_uid,)
            )
            device_result = cursor.fetchone()

            if not device_result:
                print(f"[DB] Device UID {device_uid} not found. Creating new device...")
                # Create a new device entry in the first room
                cursor.execute("SELECT id FROM rooms LIMIT 1")
                room_result = cursor.fetchone()
                room_id = room_result['id'] if room_result else 1

                cursor.execute(
                    "INSERT INTO devices (room_id, name, device_uid, type, status) VALUES (%s, %s, %s, %s, %s)",
                    (room_id, f"Sensor {device_uid}", device_uid, 'Temperature', 'active')
                )
                device_id = cursor.lastrowid
                print(f"[DB] Created new device with ID: {device_id}")
            else:
                device_id = device_result['id']

            # Insert reading
            cursor.execute("""
                           INSERT INTO readings
                               (device_id, temperature, humidity, motion_detected, recorded_at)
                           VALUES (%s, %s, %s, %s, NOW())
                           """, (device_id, temperature, humidity, motion_detected))

            # Update device last_seen
            cursor.execute("""
                           UPDATE devices
                           SET last_seen_at = NOW()
                           WHERE id = %s
                           """, (device_id,))

            mysql.connection.commit()
            print(
                f"[DB] ✓ Saved reading for {device_uid}: Temp={temperature}, Humidity={humidity}, Motion={motion_detected}")
            return True

        except Exception as e:
            print(f"[DB] ✗ Error saving reading: {e}")
            mysql.connection.rollback()
            return False
        finally:
            cursor.close()

    def _save_with_direct_db(self, device_uid, temperature, humidity, motion_detected):
        """Save using direct MySQL connection"""
        conn = mysql.connector.connect(**self.db_config)
        cursor = conn.cursor()

        try:
            # Similar logic as above but with mysql.connector
            cursor.execute(
                "SELECT id FROM devices WHERE device_uid = %s",
                (device_uid,)
            )
            device_result = cursor.fetchone()

            if not device_result:
                print(f"[DB] Device UID {device_uid} not found in database")
                return False

            device_id = device_result[0]

            # Insert reading
            cursor.execute("""
                           INSERT INTO readings
                               (device_id, temperature, humidity, motion_detected, recorded_at)
                           VALUES (%s, %s, %s, %s, NOW())
                           """, (device_id, temperature, humidity, motion_detected))

            # Update device last_seen
            cursor.execute("""
                           UPDATE devices
                           SET last_seen_at = NOW()
                           WHERE id = %s
                           """, (device_id,))

            conn.commit()
            print(f"[DB] Saved reading for device {device_uid}")
            return True

        except Exception as e:
            print(f"[DB] Error saving reading: {e}")
            conn.rollback()
            return False
        finally:
            cursor.close()
            conn.close()


from pubnub.callbacks import SubscribeCallback
from pubnub.pnconfiguration import PNConfiguration
from pubnub.pubnub import PubNub
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

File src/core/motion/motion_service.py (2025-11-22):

# https://pimylifeup.com/raspberry-pi-motion-sensor/
import time
from typing import Optional

from src.core.pubnub_client import publish_data

try:
    import RPi.GPIO as GPIO
except ImportError:
    GPIO = None


class MotionService:
    """
    Detects motion using a PIR sensor and triggers a buzzer + PubNub event.
    """

    def __init__(self, pir_pin: int = 11, buzzer_pin: int = 7, cooldown: float = 2.0):
        self.pir_pin = pir_pin
        self.buzzer_pin = buzzer_pin
        self.cooldown = cooldown
        self._gpio = GPIO
        if not self._gpio:
            raise RuntimeError(
                " Please connect to your Raspberry Pi hardware — GPIO not available."
            )
        self._setup_gpio()

    def _setup_gpio(self) -> None:
        """Configure GPIO in BOARD mode and set pin directions."""
        if not self._gpio:
            raise RuntimeError("RPi.GPIO not available")

        self._gpio.setmode(self._gpio.BOARD)
        self._gpio.setup(self.pir_pin, self._gpio.IN)  # PIR sensor output
        self._gpio.setup(
            self.buzzer_pin, self._gpio.OUT, initial=self._gpio.LOW
        )  # active buzzer

        print(
            f"[MotionService] Ready (BOARD). PIR={self.pir_pin}  BUZZER={self.buzzer_pin}"
        )

    def _beep(self, duration: float = 0.8) -> None:
        """Short beep to indicate motion."""
        self._gpio.output(self.buzzer_pin, self._gpio.HIGH)
        time.sleep(duration)
        self._gpio.output(self.buzzer_pin, self._gpio.LOW)

    def run(self, on_event: Optional[callable] = None) -> None:
        """
        - If motion detected, beep and publish an event to PubNub.
        - Optional on_event callback receives the payload dict.
        """
        print("Waiting for motion... (Ctrl+C to stop)")
        last_state = None
        try:
            while True:
                current_state = self._gpio.input(self.pir_pin)
                if current_state == 1 and last_state != 1:
                    print("[Motion] DETECTED!")
                    self._beep()

                    payload = {"event": "motion", "occupied": 1, "at": int(time.time())}
                    try:
                        publish_data(payload)  # → PubNub (channel from .env)
                    except Exception as e:
                        print(f"[Motion] PubNub publish error: {e}")
                    last_state = 1
                elif current_state == 0 and last_state != 0:
                    # no motion detected
                    print("[Motion] No motion detected.")
                    payload = {"event": "motion", "occupied": 0, "at": int(time.time())}
                    try:
                        publish_data(payload)  # → PubNub (channel from .env)
                    except Exception as e:
                        print(f"[Motion] PubNub publish error: {e}")
                    last_state = 0
                time.sleep(0.1)

        except KeyboardInterrupt:
            print("\nStopping motion service...")
        finally:
            self._gpio.cleanup()
            print("[MotionService] GPIO cleaned up.")

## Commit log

2025-10-11 Implement Registration with mysql and session support -Added POST/GET handling for /register with form validation -Created register.html that have form for register -Checked for existing usernames or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
2025-10-11 Implement secure login and finalize registration flow
    - Added /login route with hashed-password verification
    - Supported legacy plain-text passwords as a fallback
    - Fixed control flow
    - Standardized flash messages and redirects via url_for
    - Validated username/password inputs on login
    - Ensured /register inserts hashed passwords and checks username/email
    - Added success and failure html for messages
    - Added logout
2025-10-11 Create .env inside web MYSQL_HOST=127.0.0.1 MYSQL_USER=root MYSQL_PASSWORD= insert your mariaDB password MYSQL_DB=thermotrack PORT=3306
2025-10-12 Implement protected Thermo-Track dashboard layout
    Adds the primary, protected dashboard view for logged-in users, featuring the full visual design requested by the user.
    The dashboard includes:
    - A responsive, dark-themed sidebar with main navigation links.
    - A top header with the application title and a notification icon.
    - An empty grid section with placeholder cards for future room data.
    Updates `app.py` to:
    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
2025-10-18 Add base placeholder pages and global menu template
    Create the initial structure for the main application views (Reports,
    Policies, Setup, and Settings) as required for the application
    roadmap.
    The primary goal is to ensure a cohesive user experience across all
    pages by applying the new `menu.html` sidebar component globally. This
    allows for proper navigation and consistent visual feedback via the
    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
2025-10-18 voice input for thermo track text fields -Implemented voice input feature using the Web Speech API - Added dynamic mic button beside all '.tt_voiceable' input and textarea elements - Allows users to 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
2025-10-18 add detailed ThermoTrack security and privacy section -Added full security overview outlining protection of device, data transfer and data storage -Included database security with password hashing an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
2025-10-18 Add detail for the UI mock-up
    Add the prototype for the application. Describe the user connection and interaction with the data available to them through the UI
2025-10-24 Add the developed document with the hardware detail
    In the document:
    List the hardware that will be required to develop this application.Detail how the hardware will be powered and connected to the internet
2025-10-26 Add project UI and hardware detail
    - Add additional Ui improvements to the document
    - Add the circuit and fritzing diagrams
    [Thermotrack Digram Attempt2.fzz, Thermotrack first assemble before the circuit diagram.fzz]
2025-10-27 Implement dark mode
    Add complete dark/light theme switching with system preference detection
    and persistent user preferences. Create smooth transitions between themes
    while maintaining all existing functionality.
    - Add CSS custom properties for both light and dark themes
    - Implement ThemeManager class for theme state management
    - Create theme toggle button in sidebar
    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
2025-10-28 add PIR sensor and buzzer motion detection service with PubNub integration This commit is a motionService class which detects motion via a PIR sensor and triggers a buzzer alert. When motion is detec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
    Next step:
    -Test the code on PI
    -check PubNub is working
    [motion_service.py, run_motion.py]
2025-10-28 add requirements for Pi.txt file with step by step Raspberry Pi setup instructions and update README.md - Included full instructions to clone repo, install dependencies, configure environment, and ru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
2025-10-30 Implement code for the DHT22 sensor
    Write code to read temperature and humidity conditions from the DHT22 sensor.
    Include error handling to account for improper connection with hardware
    Input data logging to capture tempereture and humididty readings
    [humidity.csv]
2025-10-30 Add DHT22 sensor setup instructions to README
    Added detailed setup instructions for DHT22 sensor including hardware requirements, wiring steps, and software dependencies.
2025-10-30 Revise DHT22 Sensor Setup Guide
    Updated the DHT22 sensor setup section for clarity and organization.
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2025-11-03 change src reference to fix a personal error
    [motion_service.py]
2025-11-03 Updated data handling for sensors, and limiting sensor data to one user, removed regression, and updated databse schema and dashboard.html to match.
2025-11-03 change files to fix running issues with python
    [motion_service.py]
2025-11-03 Implement AI-powered HVAC recommendations with weather integration
    Add comprehensive AI analysis system using Google Gemini and OpenWeather API
    to provide intelligent HVAC recommendations based on both room conditions and
    external weather data.
    Key features implemented:
    - Google Gemini AI integration for smart HVAC recommendations
    - OpenWeather API integration for real-time weather data
    - Robust AI response parsing with multiple fallback strategies
    - Temporary dashboard interface for AI recommendations
    - Comprehensive error handling and fallback systems
    New files added:
    - utils/weather_gemini.py - Core AI and weather analysis engine
    - templates/ai_recommendations.html - AI recommendations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
2025-11-08 dht22: integrate PubNub publishing for temperature and humidity readings
    -Added PubNub data publishing to the DHT22 sensor logger.
    -Each sensor reading now sends temperature (°C), humidity (%), and timestamp
    to the configured PubNub channel, in addition to CSV logging and console output.
    -This enables real time monitoring of DHT22 data alongside motion sensor events
    within the unified ThermoTrack PubNub stream.
2025-11-08 dht22: integrate PubNub publishing for temperature and humidity readings
    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
2025-11-08 motion: improve motion detection handling and add friendly GPIO error
    - Updated motion_service.py to provide a clear message when run outside Raspberry Pi hardware
    - Added clean exception handling in run_motion.py for better user feedback
    - Simplified GPIO setup flow and maintained PubNub event publishing for motion/no-motion states
    - Keeps compatibility with Raspberry Pi hardware setup while improving local test experience
    [motion_service.py, run_motion.py]
2025-11-09 Fix database schema compatibility and user scoping issues
    - Fixed Python helper functions to match actual database schema
    - Updated get_rooms_summary() to use existing v_latest_device_reading view
    - Corrected get_recent_readings() to filter by rm.user_id instead of non-existent r.user_id
    - Enhanced room CRUD operations with proper user_id scoping for security
    - Added missing user creation in sample data
    - Resolved 'Unknown column user_id' errors by aligning queries with schema relationships
    Key changes:
    - Database queries now properly follow user→rooms→devices→readings chain
    - All data access is properly scoped to authenticated user
    - Room operations include user_id validation to prev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
    [motion_service.py]
2025-11-09 Fix SQL query column references in get_recent_readings()
    - Correct WHERE clause from 'r.user_id' to 'rm.user_id' in get_recent_readings()
    - Fix user filtering to use rooms table instead of readings table
    - Resolve 'Unknown column r.user_id' error by aligning with actual schema
    - Maintain proper user scoping through rooms→devices→readings chain
    The issue was that readings table doesn't contain user_id column -
    user scope is properly maintained through room relationships"
2025-11-09 Upgrade rooms card to display detailed views
    - Add individual room detail pages with comprehensive settings
    - Integrate AI recommendations directly into room cards
    - Enhance room cards with real-time metrics (temp, humidity, device count)
    - Add quick status indicators and visual feedback on room cards
    - Creat dedicated room control pages with:
    - Temperature setpoint controls with range sliders
    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
2025-11-09 Implement comprehensive temperature unit system with AI integration
    ## Features Added
    - Multi-unit temperature support (Celsius, Fahrenheit, Kelvin) with dynamic conversion
    - Room-specific temperature unit preferences stored in database
    - Temperature unit dropdown selector in room control interface
    - Real-time unit conversion across all application sections:
    - AI recommendations with unit-aware analysis
    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
2025-11-09 Add voice input validation with temperature range enforcement
    ## Voice Recognition Feature Enhancements
    - Implement temperature range validation for voice inputs
    - Add automatic clamping to min/max values when out of bounds
    - Enhance voice feedback with visual notifications for validation results
    - Improve temperature extraction from various speech patterns
    ## Validation Features
    - Voice inputs automatically clamped to 16-28°C range (or converted equivalents)
    - Real-time feedback when values are adjusted due to range limits
    - Visual indicators for successful and failed voice recognition
    - Support for different temperature unit contexts
    ## User Experience
    - Clear feedback when temperature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
2025-11-11 add DHT22 temperature/humidity and PIR motion monitoring with buzzer and PubNub logging
    - Initialize DHT22 sensor on Raspberry Pi for temperature & humidity readings
    - Initialize PIR sensor and active buzzer for motion detection
    - Log readings to CSV file (`data/humidity.csv`)
    - Publish sensor data and motion events to PubNub
    - Added simple buzzer beep on motion detection with cooldown
    - Handles GPIO cleanup and errors for safe shutdown
    [humidity.csv]
2025-11-14 Add responsive search bar with real-time filtering
    ## Features
    - Real-time search across rooms, devices, sensor logs, and locations
    - Filter buttons to search specific sections (Rooms, Sensor Logs, All)
    - Responsive design that works on all screen sizes
    - Visual feedback with result counts and highlighted matches
    - Keyboard shortcuts (Ctrl+K to focus search, Escape to clear)
    ## Search Capabilities
    - Room names and locations
    - Device names and UIDs
    - Sensor values (temperature, humidity)
    - Motion detection status
    - Device types and categories
    - Clear visual feedback for search results
    - Empty state handling with helpful messages
    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
2025-11-14 Implement robust Raspberry Pi hardware monitoring system with sensor fusion
    ## Hardware Integration
    - Unify sensor monitoring system for PIR motion detection and DHT22 temperature/humidity
    - GPIO conflict resolution with proper pin mapping for actuators and sensors
    - Mock GPIO support for development and testing without physical hardware
    - Robust error handling for sensor failures and hardware unavailability
    ## Core Features
    - Real-time motion detection with PIR sensor and cooldown logic
    - Temperature/humidity monitoring with DHT22 sensor
    - Smart actuator control: LED/buzzer for motion alerts, fan for temperature control
    - PubNub integration for real-time data publishing to cloud dashboard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
    [dht22_logger.py, sensor_logic.py]
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2025-11-15 Upadate admin panel with request management and role-based navigation
    - Implement comprehensive room request management system for admin users
    - Add role-based access control with session-based admin verification
    - Create admin panel with request filtering (status, user, type) and compact card design
    - Update request workflow: pending → viewed → approved/denied with notifications
    - Fix user request submission from room pages with temperature/fan controls
    - Fix real-time notification system with bell indicator and status updates
    - Improve UI with compact request cards, filter system, and better empty states
    - Fix database connection issues in admin verification function
    - Add debug endpoi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
2025-11-15 fix: handle None values in weather AI fallback recommendations
    - Fix TypeError when room temperature is None in _get_fallback_recommendations
    - Add proper null handling with default values in room data processing
    - Use COALESCE in SQL queries to provide defaults for NULL avg_temp/avg_humidity
    - Ensure ai_room_input always contains valid numeric values for temperature and humidity
    - Add robust error handling to prevent None comparison issues in fallback logic
    Resolves: TypeError: '>' not supported between instances of 'NoneType' and 'int'"
2025-11-16 feat: complete sensor integration with database bridge
    - Add PubNub subscriber service to bridge sensor data to MySQL database
    - Integrate DHT22 temperature/humidity sensor with real-time monitoring
    - Add PIR motion sensor with LED/buzzer actuator control
    - Implement fan control based on temperature thresholds
    - Update sensor_logic.py with proper device UIDs and actuator logic
    - Add database handler for storing sensor readings
    - Support both Flask MySQL and direct database connections
    - Complete end-to-end data flow: Sensors → PubNub → Database → Web UI
    Hardware integration:
    - GPIO 4 (DHT22) for temperature/humidity
    - GPIO 17 (PIR) for motion detection
    - GPIO 27 (Buzzer) and GPIO 22 (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
    [pubnub_subscriber.py, sensor_logic.py]
2025-11-17 feat: Implement technician super-admin role with full user management
    - Add 'Alter Role' column exclusively for technicians with full role control
    - Technicians can promote/demote any user including admins (admin → user, user → admin, etc.)
    - Admins no longer see technicians in user management table
    - Implement role-based data filtering: technicians see all users, admins see non-technicians
    - Add self-role change protection to prevent accidental self-demotion
    - Maintain security: technicians cannot change their own role
    Features:
    - Separate 'Alter Role' column visible only to technicians
    - Full role dropdown with all options for technicians
    - Role-based user visibility (admins don't see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
2025-11-19 fix: Resolve search functionality in setup page
    - Replace inline style manipulation with CSS class toggling for table rows
    - Add !important rule to ensure .hidden class properly hides table rows
    - Update count logic to check for hidden class instead of display style
    - Fix clear search functionality to use class removal
    - Maintain all search filtering logic while fixing visual display issues
    - Ensure table rows properly show/hide based on search criteria
2025-11-19 Work in progress: update sensor logic and humidity data
    [humidity.csv]
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2025-11-19 feat: implement auto-refresh for notification table
    - Add automatic refresh when page becomes visible (tab switch)
    - Implement cache busting with timestamps to prevent stale data
    - Add 30-second periodic refresh when page is active
2025-11-20 feat: add user profile viewing modal for admin/technician
    - Implement responsive user profile modal component
    - Fix loading state issues by preserving DOM structure
    - Add proper error handling and user feedback
    - Include role-based styling with color-coded badges
    * CSS touch up to align the 'actions' table column with the 'add to rooms' button
    Testing:
    - Verified modal opens correctly from user management table
    - Tested responsive behavior across mobile, tablet, desktop
    - Confirmed API data population works correctly
    - Validated role-based access controls
    - Checked error handling for missing users/data
2025-11-20 fix: Temperature unit conversion and display
    - Fix client-side temperature conversions between Celsius/Fahrenheit/Kelvin
    - Add unit toggle for all user roles with localStorage persistence
    - Ensure all temperature displays update correctly when units change
    - Fix input range and slider conversions
    - Maintain Celsius as base unit for data integrity
2025-11-20 Fix dashboard loading issue Changes: - Replaced AVG() calculations in get_rooms_summary() with subqueries that fetch the newest reading (ORDER BY recorded_at DESC LIMIT 1). - Ensures dashboard always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
    This makes dashboard data consistent with live hardware updates.
2025-11-20 feat: Add a hardware controller with GPIO management
    - Implement HardwareController class with fan/buzzer control
    - Add temperature-based auto fan control
    - Include hardware presets and status monitoring
    - Register cleanup with "atexit" for proper GPIO handling
    [sensor_logic.py]
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2025-11-21 fix: center-align all table headers and content
    - Center-align all table headers across My Rooms, Available Rooms, All Rooms, and Devices tables
    - Center-align all table content including room names, device names, status badges, and action buttons
    - Ensure action buttons in Actions column are properly centered with justify-center
    - Add consistent justify-center classes to inline-flex elements for proper centering
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2025-11-22 Implement new PubNub based fan & buzzer control system and remove old GPIO hardware controller
    - Replaced old hardware_controller based fan logic with a fully new PubNub command architecture.
    - Added new `/api/hardware/fan` and `/api/hardware/buzzer` API endpoints that publish PubNub commands (`fan_on`, `fan_off`, `buzzer_on`, `buzzer_off`) instead of controlling GPIO directly.
    - Implemented new Raspberry Pi listener (`pi_command_listener.py`) to receive PubNub commands and trigger GPIO14 (fan) and GPIO27 (buzzer).
    - Cleaned up old unused hardware_controller code and removed direct GPIO calls from the Flask app.
    - Established clean separation between server (Flask) and device (Pi) responsibi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
    [pi_command_listener.py]
2025-11-22 Add full fallback mode for DHT22 + PIR monitoring
    - Implemented SmartHomeMonitor class with no dependency on hardware_controller
    - Added direct GPIO fan control using threshold TEMP_THRESHOLD_C
    - Integrated PubNub fallback publishing for sensor/motion events
    - Added MockGPIO fallback to allow execution without real GPIO hardware
    - Added DHT22 read handling with safe failure recovery
    - Added temperature-based fan logic:
    - Fan ON when temp >= 24°C
    - Fan OFF below 24°C
    - Fan output currently simulated until relay module is installed
    [pi_command_listener.py, sensor_logic.py]
2025-11-22 Fix room summary to show real time temperature and humidity -Updated get_rooms_summary() to use v_latest_device_reading for accurate real time temperature and humidity.
2025-11-22 Prevent setup page crash by converting datetime to string before .lower() -Change: - Replaced `(device.last_seen_at or '').lower()` with `(device.last_seen_at|string).lower() if device.last_seen_at e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
    [motion_service.py]
2025-11-22 fix the fan code not finding the module
    [pi_command_listener.py]
2025-11-24 feat: develop collapsible sidebar with theme-switching logo
    - Replace text with dynamic logo image (light/dark themes)
    - Persistent collapse state using localStorage
    - Smooth animations with proper icon centering
    - Logo remains visible for toggle functionality
    - No auto-expand on page navigation
2025-11-24 Fix fan control with PubNub commands and auto-mode support - Added full manual fan control using PubNub commands (fan_on / fan_off) - Updated Pi command listener to use correct GPIO pin (BCM 17) - Ad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
    [pi_command_listener.py]
2025-11-24 Integrate full fan auto mode + manual PubNub control into sensor logic -Integrated manual fan and buzzer control via PubNub commands (fan_on, fan_off, buzzer_on, buzzer_off). -Implemented auto mode f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
    [sensor_logic.py]
2025-11-24 Add a loud beep to the buzzer when motion is detected in sensor_logic.py. -added a loud beep to the buzzer when motion is detected in sensor_logic.py.
    [sensor_logic.py]
2025-11-25 feat: complete policy management system with presets and energy rules
    - Relocated Quick Presets from room.html to policies.html for better organization
    - Added 4 new energy policy cards with interactive toggle functionality:
    * Weekend Deep Sleep - Extended energy savings during weekends
    * CO2 Demand Control - Smart ventilation based on air quality
    * Solar Gain Compensation - Automatic temperature adjustment for solar exposure
    * Frost Protection - Prevents freezing in unoccupied spaces
    - Implemented dynamic toggle system with visual feedback showing active/inactive states
    - Added toast notification system for immediate user feedback on policy changes
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2025-11-29 This update introduces a complete visual overhaul of the authentication experience across Thermo-Track. The login, registration, and index pages have been redesigned to match a unified modern theme c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
2025-11-30 feat: implement custom role change modal to replace the default
    - Add role change confirmation modal with user profile display
    - Implement role descriptions and visual role comparison with badges
    - Add toast notifications for user feedback
    - Role change modal shows user info, current/new roles with badges
    - Detailed role descriptions for better user understanding
    - Visual feedback for all user actions
    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
2025-12-01 Add full reports module: filtering, CSV export, PDF summary, and UI polish
    - Implement download_reports_summary() PDF generator
    - Improve export_reports_csv() with filter support
    - Apply unified filter state via request.args
    - Update reports.html (UI polish, preserved filters, cleaner summary cards)
    - Connect PDF + CSV actions to active filters
    - Minor style fixes for consistency with ThermoTrack theme
2025-12-02 fix: Revert theme code to prevent flashing while in light mode
    - Restore old theme code that ensures there is no flashing when switching pages in light mode
2025-12-03 Add PWM buzzer ON/OFF sound system and integrate into SmartHomeMonitor - Added PWM based buzzer sound system with rising (ON) and falling (OFF) tones. - Introduced `beep_on_sound()` and `beep_off_sou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
    [sensor_logic.py]

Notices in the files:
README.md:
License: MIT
